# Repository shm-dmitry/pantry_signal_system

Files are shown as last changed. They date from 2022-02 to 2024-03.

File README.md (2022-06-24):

This is signal system for pantry.
It will control climate of pantry to smart house.

It will uses autonomous power system
1. car battery on 12v
2. temporary Li-Ion battary on 12v for charging primary battery
3. internal battery (6V..15V) which will used in case of primary and reserve 12V battery discharged. Used to send power alarm to smart house
4. Auto battary hot switch
5. Control over-discharge of all batteries
6. Provide information of current voltage to controller
7. Small current consumption. I plan to charge main battary once per ~6 month. 

It will collect and send next information (incl alarms):
1. Inside flooding alarm
2. Outside flooding alarm
3. Inside humidity level
4. Inside temperature
5. Inside light level
6. Open door alarm
7. Current voltage of all batteries
8. Current battery in use
9. Both 12V batteries discharged alarm 

It will automatically switch on air-drier basing on humidity level

It will have air fan system
1. Manual swotch on
2. Manual swotch off
3. Auto switch off after ~20 minutes

It will send all collected information to smart house system using LoRa channel

Project status

| Hardware | Status |
| --- | --- |
| Supply module | OK |
| Supply module :: Supply controller | OK |
| Logic module :: Flooding sensors | OK |
| Logic module :: Light sensor | OK |
| Logic module :: display | OK |
| Logic module :: humidity and temperature | OK |
| Logic module :: air dryer | OK |
| Logic module :: LoRa transmitter | OK |
| Logic module :: Open door alarm | OK |
| Logic module :: Wakeup button | OK |
| Air fan module | OK |
| LoRa receiver and smart house integration | OK |

| Firmware | Status |
| --- | --- |
| Supply controller | OK |
| Logic controller :: flooding sensors | OK |
| Logic controller :: light sensor | OK |
| Logic controller :: display | OK |
| Logic controller :: humidity and temperature | OK |
| Logic controller :: air dryer | OK |
| Logic controller :: LoRa transmitter | OK |
| Logic controller :: Open door alarm | OK |
| Logic controller :: Wakeup button and deep sleep mode | OK |
| Logic controller :: Integration with supply controller | OK |
| LoRa receiver and smart house integration | OK |

| Board | Status |
| --- | --- |
| Supply board | OK |
| logic module board | OK |
| fan board | OK |
| LoRa Receiver | OK |

| 3D models | Status |
| --- | --- |
| Supply board box | OK |
| Logic model box | OK |
| Air dryer | OK |
| Fan box | OK |
| Fan air intake | OK |
| LoRa receiver box | no |

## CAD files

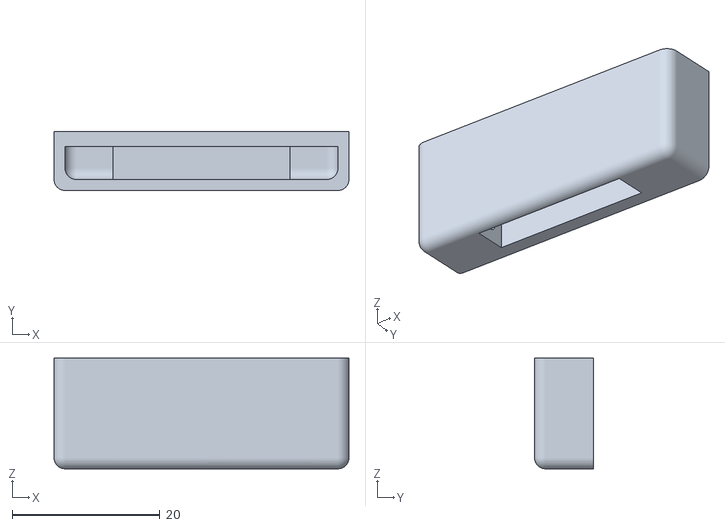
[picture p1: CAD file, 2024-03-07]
3d_models/reed_switch-reed-switch-holder.stl
40.0 x 8.00 x 15.0

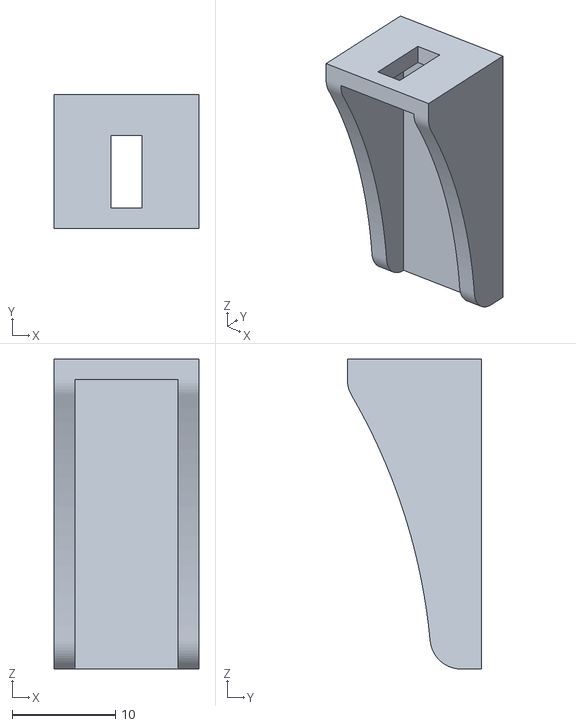
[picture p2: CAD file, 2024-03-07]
3d_models/reed_switch-magnet-holder.stl
14.0 x 13.0 x 30.0

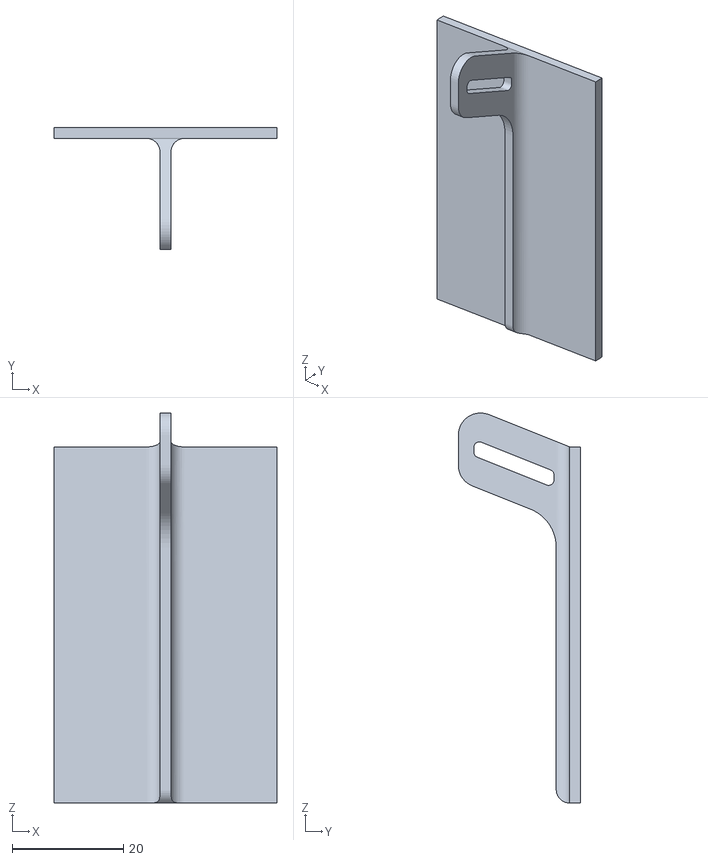
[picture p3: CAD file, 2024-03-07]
3d_models/reed_switch-magnet-holder-v3.stl
40.0 x 22.0 x 70.1

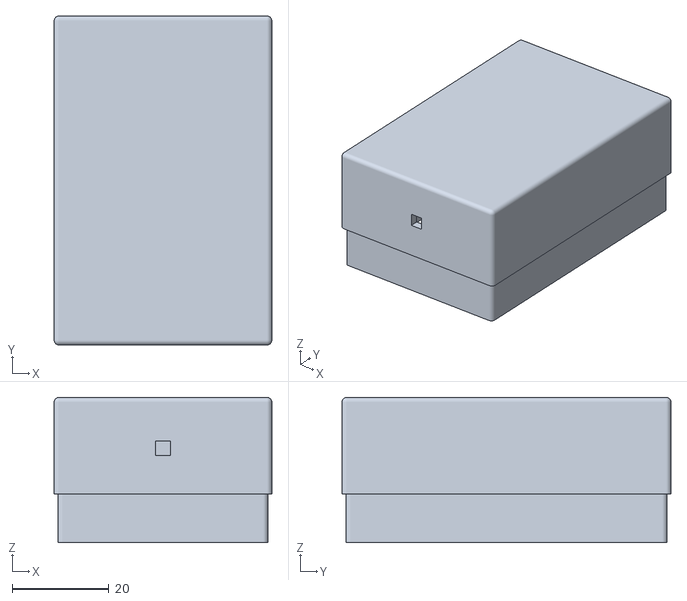
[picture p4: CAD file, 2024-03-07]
3d_models/lora_receiver-top.stl
45.0 x 68.0 x 30.0

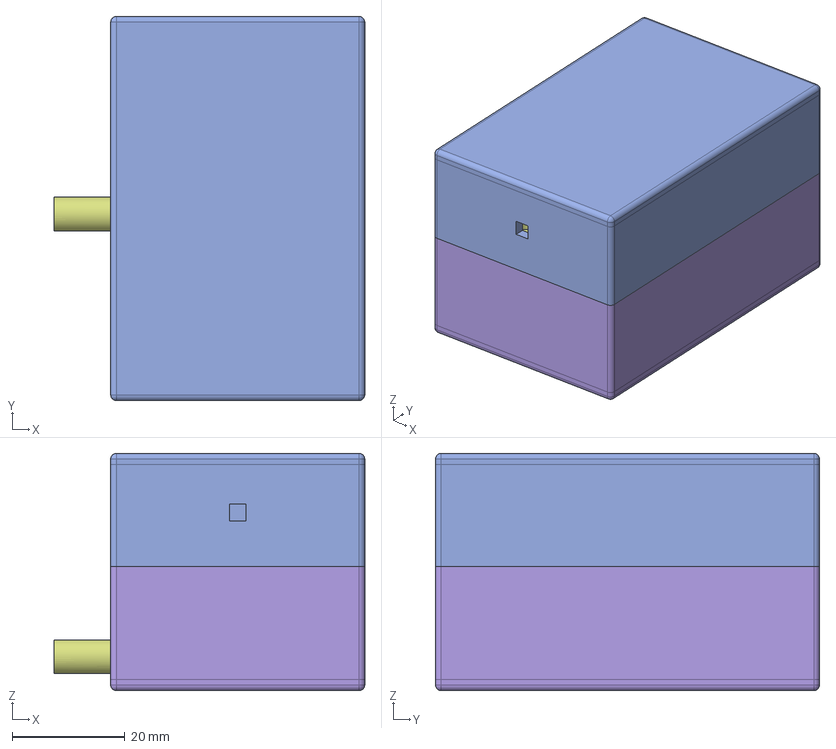
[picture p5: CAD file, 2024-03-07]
3d_models/lora_receiver.FCStd
55.0 x 68.0 x 42.0 mm
board
bottom
top

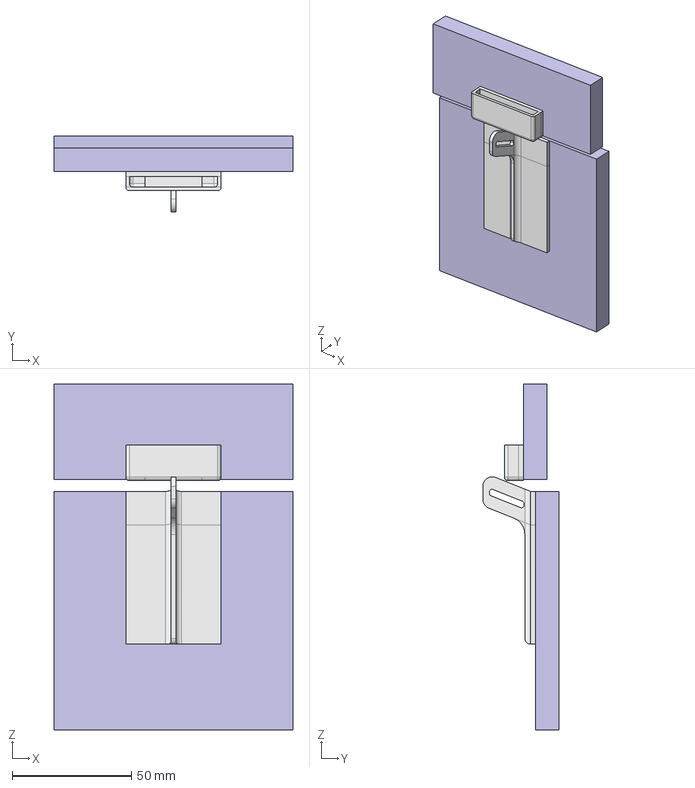
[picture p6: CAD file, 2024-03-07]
3d_models/reed_switch.FCStd
100.0 x 32.0 x 145.0 mm
reed-switch-holder
magnet-holder-v3

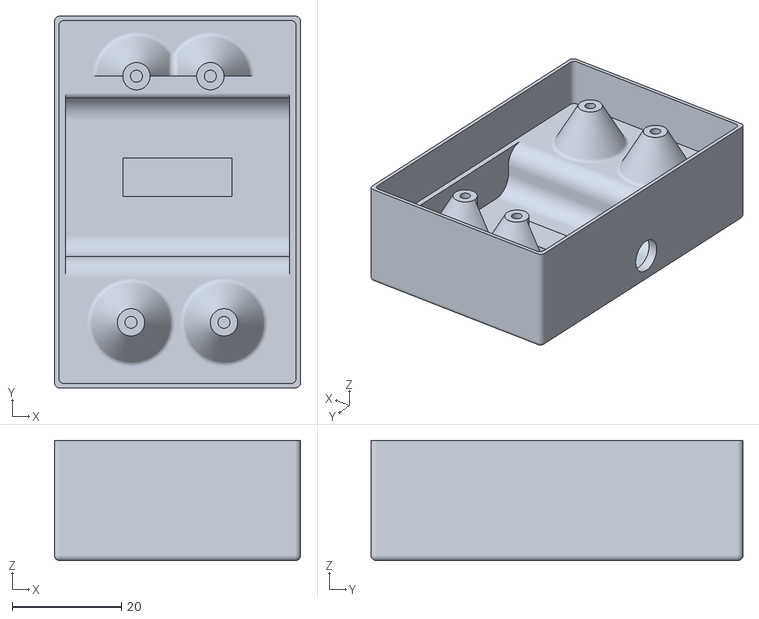
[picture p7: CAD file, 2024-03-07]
3d_models/lora_receiver-bottom.stl
45.0 x 68.0 x 22.0

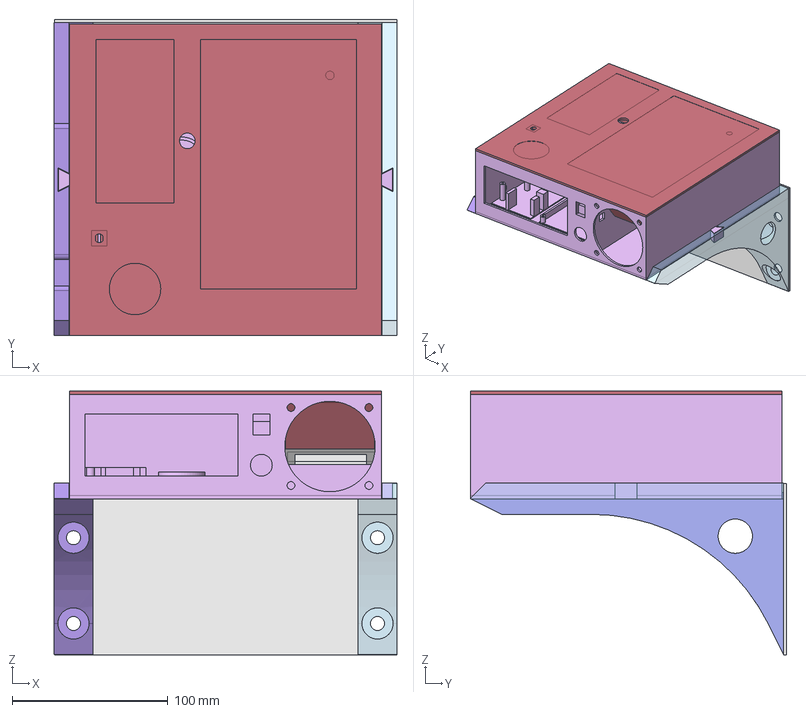
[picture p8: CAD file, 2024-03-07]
3d_models/pantry_box.FCStd
220.0 x 203.0 x 169.1 mm
cup
leg-left
leg-right-base
cilicogel-box
drill-mask

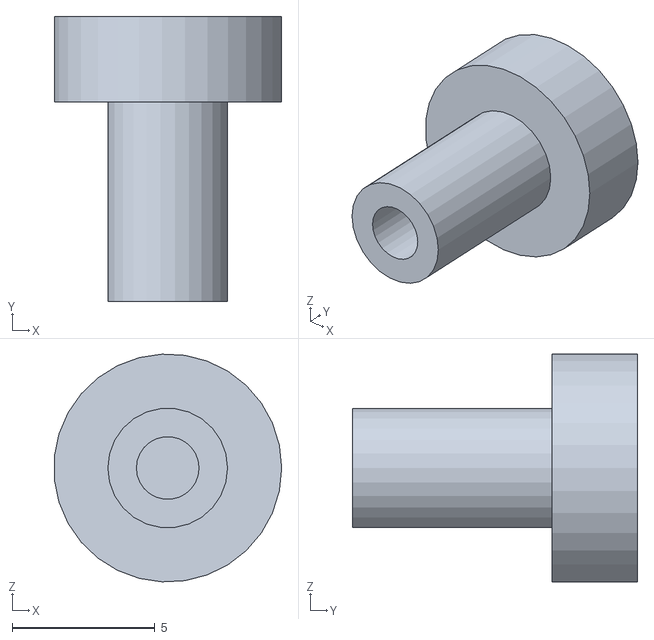
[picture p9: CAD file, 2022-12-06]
3d_models/pantry_box-pin.stl
7.98 x 10.0 x 7.99

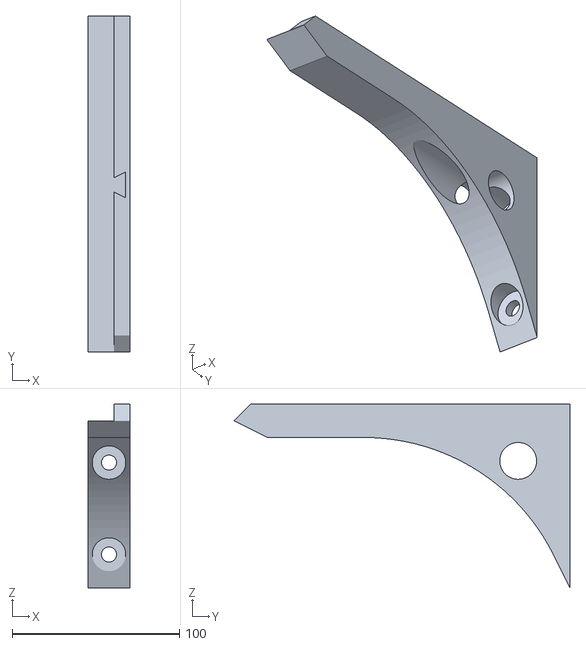
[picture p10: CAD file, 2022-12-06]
3d_models/pantry_box-leg-right.stl
25.0 x 201.0 x 110.0

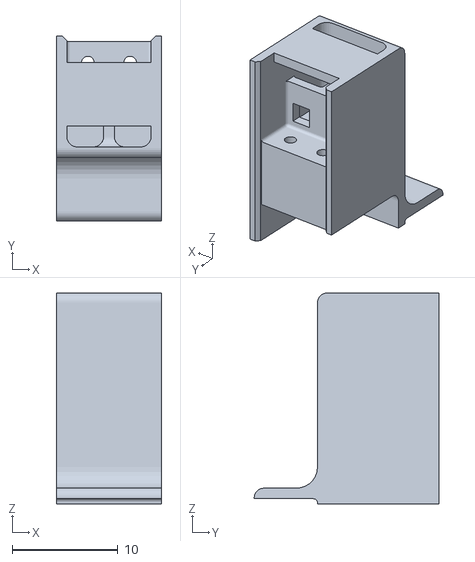
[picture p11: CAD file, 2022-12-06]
3d_models/flooding-sensor-left-side.stl
10.0 x 17.5 x 20.0

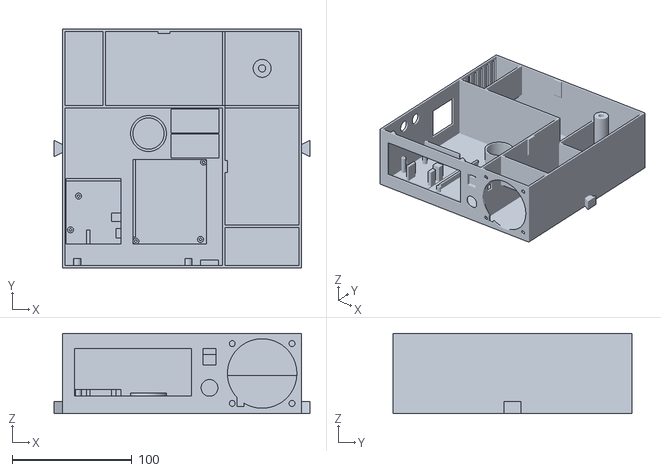
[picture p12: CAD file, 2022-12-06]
3d_models/pantry_box-box.stl
214.0 x 200.0 x 67.0

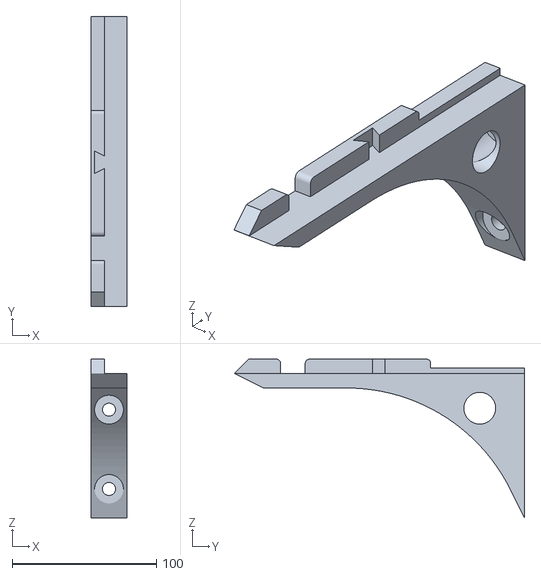
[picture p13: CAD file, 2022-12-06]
3d_models/pantry_box-leg-left.stl
25.0 x 201.0 x 110.0

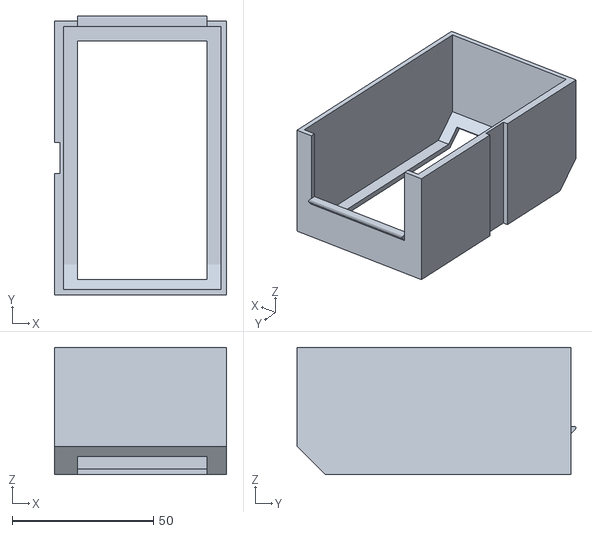
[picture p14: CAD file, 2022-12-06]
3d_models/pantry_box-cilicogel-box.stl
61.0 x 98.8 x 45.0

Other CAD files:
3d_models/flooding-sensor.FCStd
3d_models/pantry_box-cup.stl
3d_models/flooding-sensor-right-side.stl
3d_models/internal-flooding-sensor.FCStd
3d_models/23a-battery-container-box.stl
3d_models/23a-battery-container.FCStd
3d_models/air-dryer-box.stl
3d_models/air-dryer-container-cup.stl
3d_models/air-dryer-container.stl
3d_models/air-dryer-cup.stl
3d_models/air-dryer-pin.stl
3d_models/air-dryer.FCStd
3d_models/air-fan-box-box.stl
3d_models/air-fan-box-top.stl
3d_models/air-fan-box.FCStd
3d_models/air-fan-income-cap-support.stl
3d_models/air-fan-income-cap.stl
3d_models/air-fan-income-filter.stl
3d_models/air-fan-income-plate.stl
3d_models/air-fan-income-support.stl
3d_models/air-fan-income-top.stl
3d_models/air-fan-income.FCStd
3d_models/air-fan-outcome-cup.stl
3d_models/air-fan-outcome-filter.stl
3d_models/air-fan-outcome-plate.stl
3d_models/air-fan-outcome-support.stl
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

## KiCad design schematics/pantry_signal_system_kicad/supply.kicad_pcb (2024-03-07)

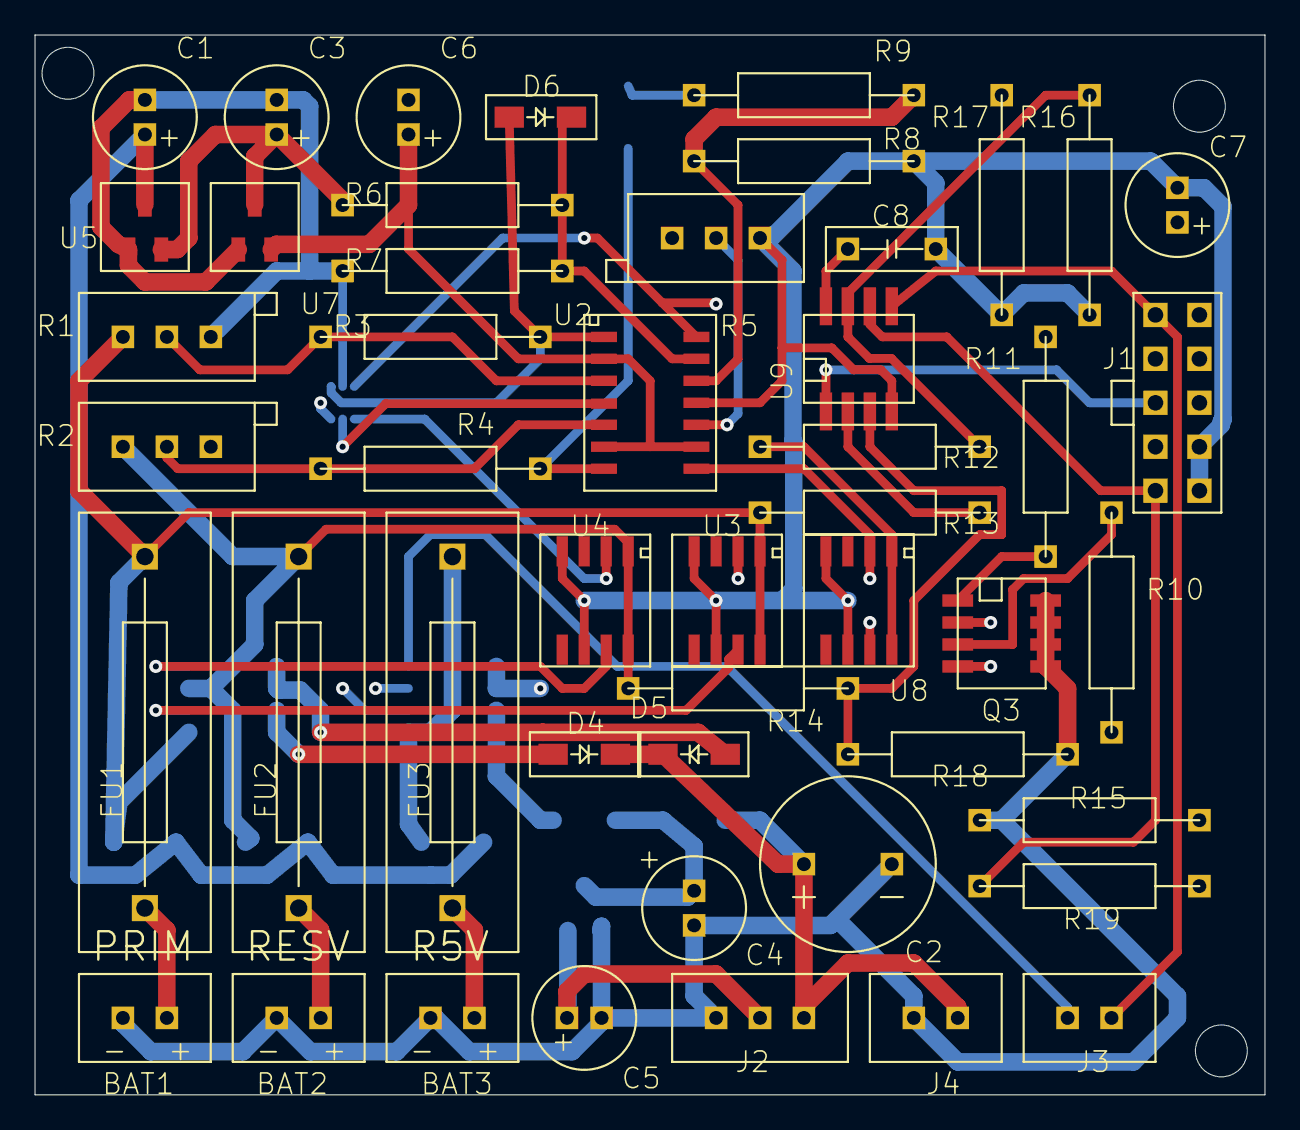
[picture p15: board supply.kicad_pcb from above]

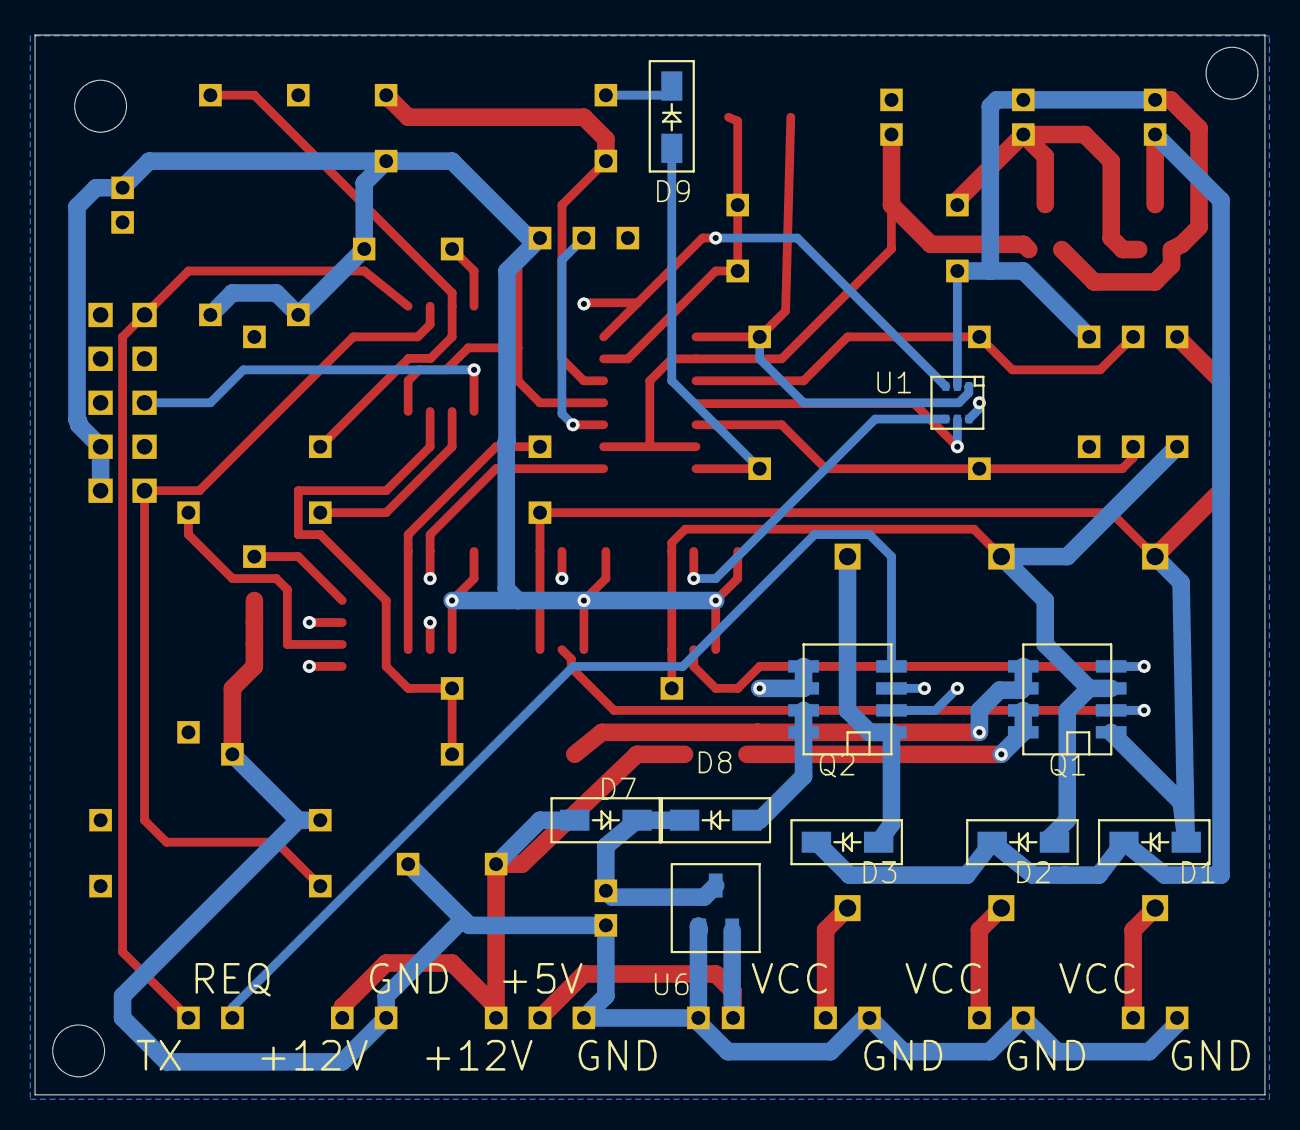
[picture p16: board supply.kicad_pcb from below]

Board: 4 copper layers, 71.1 x 61.3 mm, 61 parts (10 on the bottom side), 42 nets.

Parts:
@HOLE0, @HOLE1, @HOLE2: (no value)
BAT1, BAT2: 12V ... 15V; BATTERY
BAT3: 10V ... 15V; BATTERY
C1, C3, C4, C5, C6, C7: 10 uF; C-MINI-5X7
C2: 1000 uF; C
C8: 0.1 uF; C-1
D1, D2, D3, D4, D5, D6, D7, D8, D9: MBR130LSFT1G; D-SOD-123FL
FU1, FU2: H520PT / 1A; FU
FU3: H520PT / 0.5A; FU
J1: USBASP_PIN
J2: JST-XH254-3P
J3, J4: JST-XH254-2P
Q1, Q2, Q3: FDS4935A; SO-8
R1, R2, R5: 2M; RD-3296W-1-205LF
R3, R4, R6, R8, R9, R12, R13, R14: 2M; R
R7, R16, R17, R18: 1M; R
R10, R15: 10K; R
R11: 3K; R
R19: 620; R
U1: NC7WZ04; SC70
U2: AD8544SO-14; SO-14
U3, U4, U8: FAN73611; SOIC-8
U5, U6: MCP1703T-5002E/CB; SOT-23A
U7: MCP1703T-3302E/CB; SOT-23A
U9: ATTINY13SO-8-209; SO-8-209

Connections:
+5V: C5.PLUS, J2.PIN2, Q2.P3, U6.P2
+12V: C2.PIN_PLUS, D4.CATHODE, D5.CATHODE, D7.ANODE, J2.PIN1, J4.PIN2, R5.P2
BAT1: BAT1.PLUS, FU1.P$1
BAT2: BAT2.PLUS, FU2.P$1
BAT3: BAT3.PLUS, FU3.P$1
CURRENT_SUPPLY_IN_USE: J1.MISO, R19.P$2, U9.P6
GND: BAT1.MINUS, BAT2.MINUS, BAT3.MINUS, C1.MINUS, C2.PIN_GND, C3.MINUS, C4.MINUS, C5.MINUS, C6.MINUS, C7.MINUS, C8.P$2, J1.GND, J1.GND1, J2.PIN3, J4.PIN1, Q3.P5, Q3.P6, Q3.P7, Q3.P8, R1.P2, R2.P2, R5.P1, R7.P$1, R8.P$2, R15.P$1, R16.P$1, R17.P$1, R18.P$1, U1.P2, U2.P11, U3.P_4, U3.P_6, U4.P_4, U4.P_6, U5.P1, U6.P1, U7.P1, U8.P_4, U8.P_6, U9.P4
IS_12V_POWER_OK: R5.P3, U2.P10
IS_ENABLE_RESERVE_+5V_INV: Q3.P2, U2.P8, U8.P_2
IS_PRIMARY_BATTERY_OK: D6.ANODE, R3.P$2, U1.P1, U2.P1
IS_RESERVE_BATTERY_OK: D9.ANODE, R4.P$1, U2.P7
IS_USE_RESERVE_BATTERY: Q3.P4, U1.P3, U2.P14
unnamed: C1.PLUS, D1.CATHODE, D2.CATHODE, D3.CATHODE, U5.P3
unnamed: D6.CATHODE, R6.P$2, R7.P$2, U2.P13
unnamed: R1.P3, R3.P$1, U2.P3
unnamed: C4.PLUS, D7.CATHODE, D8.CATHODE, U6.P3
unnamed: R2.P3, R4.P$2, U2.P5
unnamed: R8.P$1, R9.P$1, U2.P12
unnamed: D4.ANODE, Q1.P7, Q1.P8
unnamed: D5.ANODE, Q1.P5, Q1.P6
unnamed: J1.RST, U9.P1
unnamed: U1.P6, U3.P_2
unnamed: U1.P4, U4.P_2
unnamed: Q3.P3, R10.P$1
unnamed: D8.ANODE, Q2.P7, Q2.P8
unnamed: Q3.P1, R11.P$1
unnamed: D9.CATHODE, R9.P$2
unnamed: C7.PLUS, R10.P$2, R11.P$2, R15.P$2, R19.P$1
PRIMARY_SUPPLY_12V: D1.ANODE, FU1.P$2, Q1.P1, R1.P1, R13.P$2, U3.P_1, U3.P_8
PRIMARY_VOLTAGE_LEVEL: R13.P$1, R17.P$2, U9.P2
REQUEST_SUPPLY_MEASURE_INV: J3.PIN2, Q2.P4
RESERVE_+5V_LEVEL: J1.SCK, R12.P$1, R16.P$2, U9.P7
RESERVE_+5V_SUPPLY: D3.ANODE, FU3.P$2, Q2.P1, R12.P$2, U8.P_1, U8.P_8
RESERVE_SUPPLY_12V: D2.ANODE, FU2.P$2, Q1.P3, R2.P1, R14.P$2, U4.P_1, U4.P_8
RESERVE_VOLTAGE_LEVEL: R14.P$1, R18.P$2, U9.P3
SUPPLY_AVR_+5V: C8.P$1, J1.VCC, Q2.P5, Q2.P6, U9.P8
SUPPLY_CONTROL_3V3: C6.PLUS, U2.P2, U2.P6, U2.P9, U7.P2
SUPPLY_CONTROL_+5V: C3.PLUS, R6.P$1, U1.P5, U2.P4, U5.P2, U7.P3
SUPPLY_UART_TX: J1.MOSI, J3.PIN1, U9.P5
USE_PRIMARY_BATTERY: Q1.P2, U3.P_7
USE_RESERVE_5V_BATTERY: Q2.P2, U8.P_7
USE_RESERVE_BATTERY: Q1.P4, U4.P_7

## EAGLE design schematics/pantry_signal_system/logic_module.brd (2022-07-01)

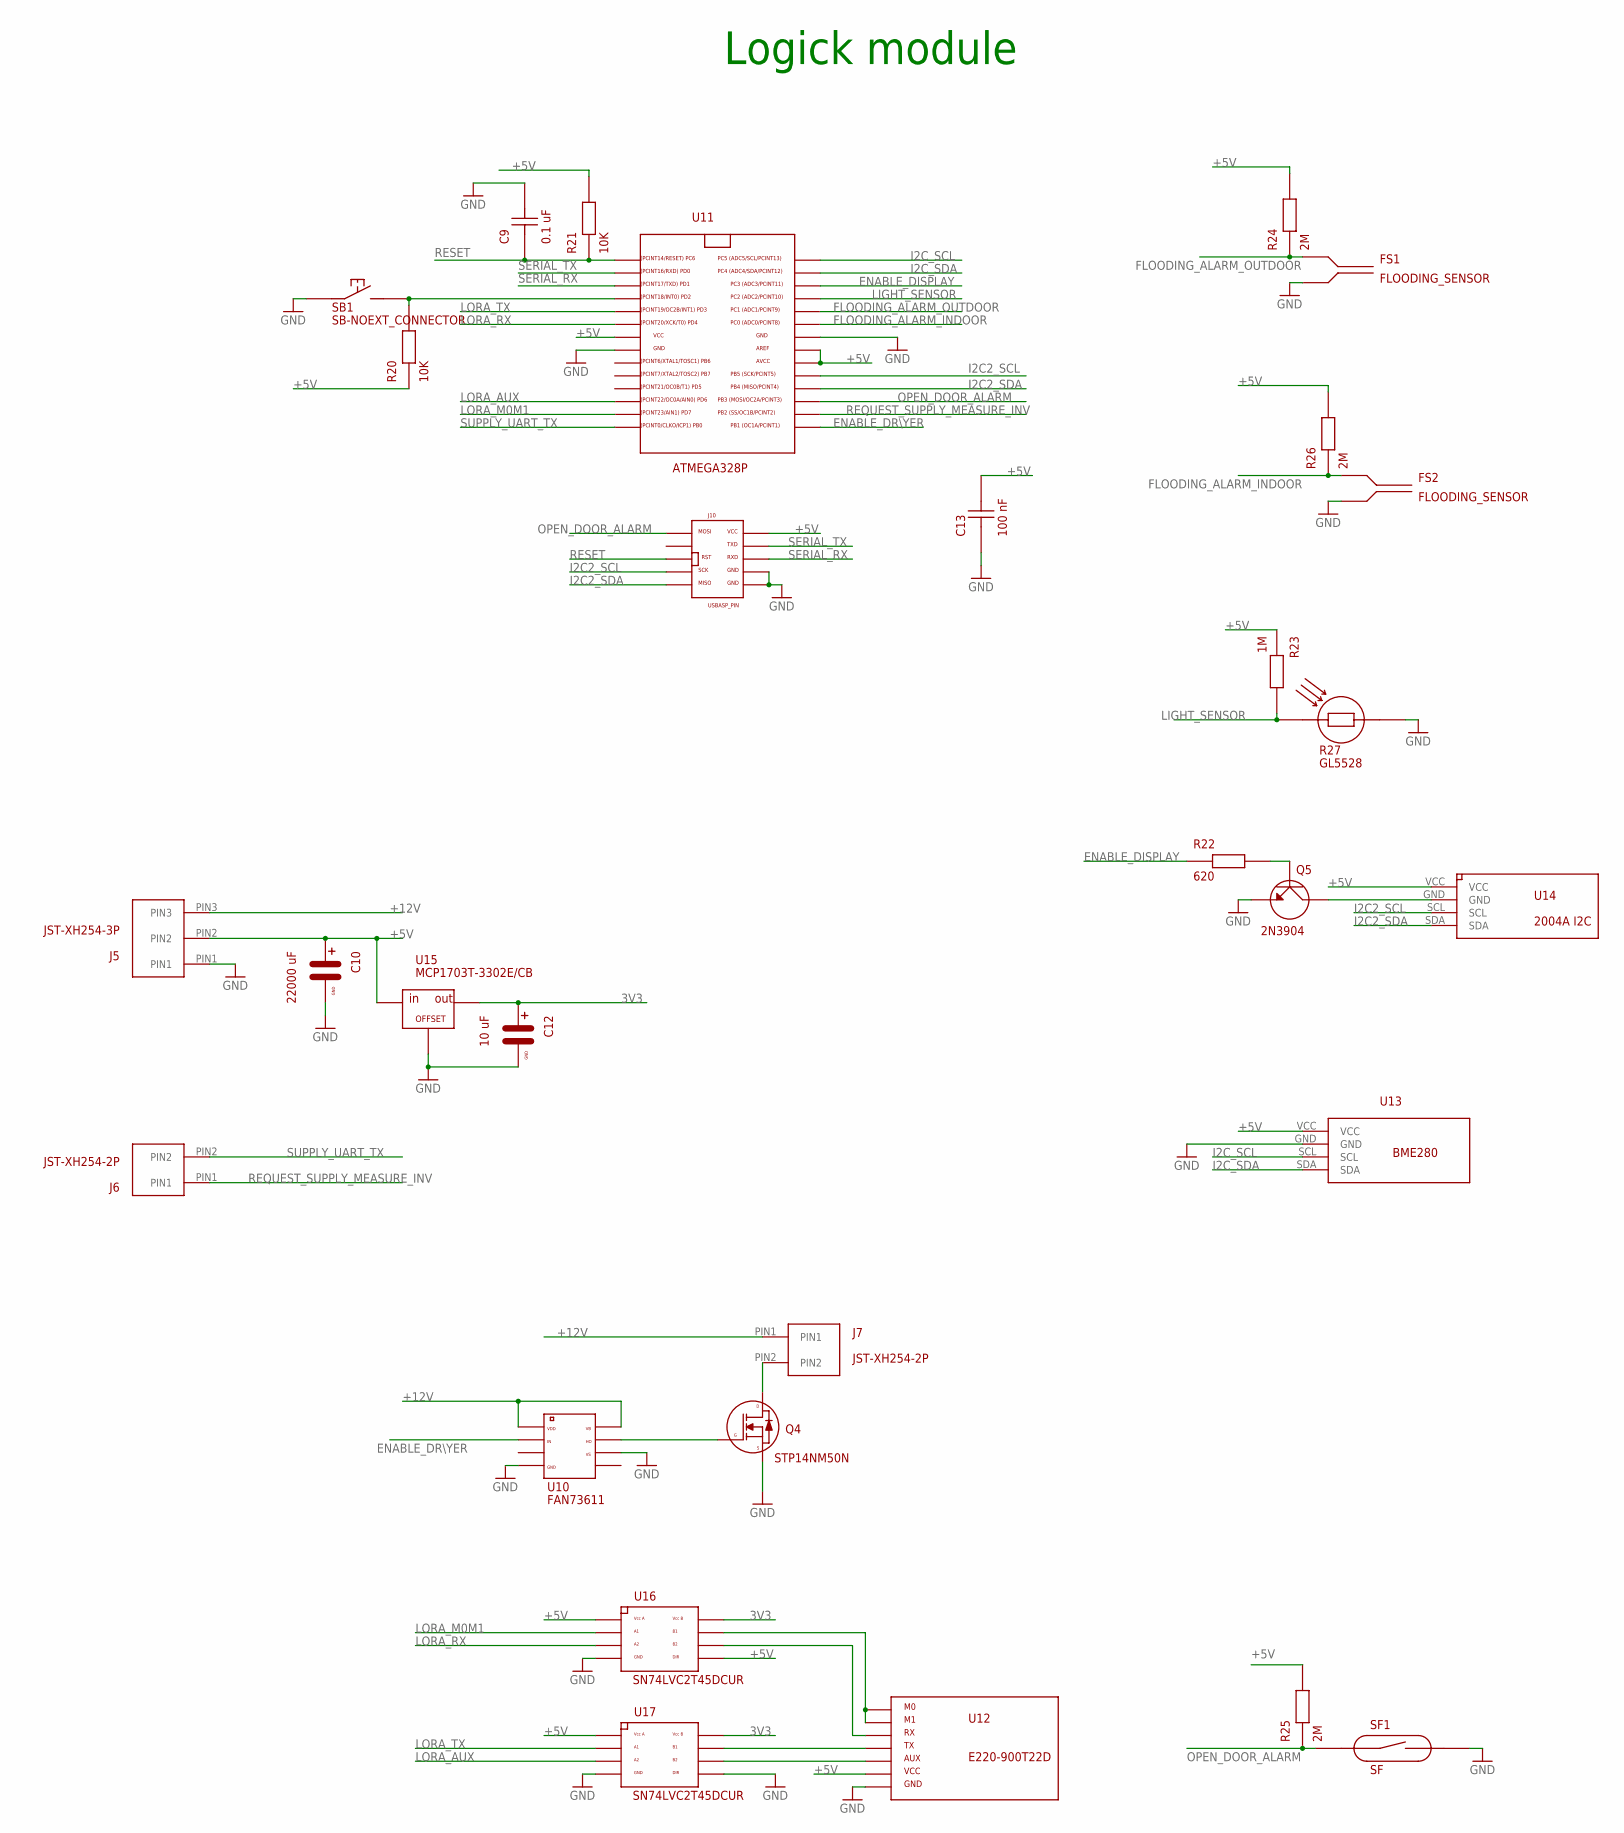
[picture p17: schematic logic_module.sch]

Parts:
C9: 0.1 uF; C-1
C10: 22000 uF; C-MINI-5X7
C12: 10 uF; C-MINI-5X7
C13: 100 nF; C-1
FS1, FS2: FLOODING_SENSOR
J5: JST-XH254-3P
J6, J7: JST-XH254-2P
J10: USBASP_PIN
Q4: STP14NM50N; MOSFET_N
Q5: 2N3904; TRANSISTOR
R20, R21: 10K; R
R22: 620; R
R23: 1M; R
R24, R25, R26: 2M; R
R27: GL5528; RF
SB1: SB-NOEXT_CONNECTOR; SB-EXT
SF1: SF
U10: FAN73611; SOIC-8
U11: ATMEGA328P
U12: E220-900T22D; LORA
U13: BME280BME280-CONNECTOR-ONLY; BME280-CONNECTOR-ONLY
U14: 2004A I2C; I2C_DISPLAY
U15: MCP1703T-3302E/CB; SOT-23A
U16, U17: SN74LVC2T45DCUR; VSSOP-8

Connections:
3V3: C12.PLUS (PIN_PLUS), U15.P2 (OUT), U16.P8 (VCCB), U17.P8 (VCCB)
+5V: C10.PLUS (PIN_PLUS), C13.P$2, J5.PIN2, J10.VCC, R20.P$1, R21.P$2, R23.P$1, R24.P$2, R25.P$2, R26.P$2, U11.AREF, U11.AVCC, U11.VCC, U12.VCC, U13.VCC, U14.VCC, U15.P3 (IN), U16.P1 (VCCA), U16.P5 (DIR), U17.P1 (VCCA)
+12V: J5.PIN3, J7.PIN1, U10.P_1 (VDD), U10.P_8 (VB)
ENABLE_DISPLAY: R22.P$1, U11.PC3
ENABLE_DR\YER: U10.P_2 (IN), U11.PB1
FLOODING_ALARM_INDOOR: FS2.P$1, R26.P$1, U11.PC0
FLOODING_ALARM_OUTDOOR: FS1.P$1, R24.P$1, U11.PC1
GND: C9.P$2, C10.MINUS (PIN_GND), C12.MINUS (PIN_GND), C13.P$1, FS1.P$2, FS2.P$2, J5.PIN1, J10.GND, J10.GND1, Q4.S, Q5.E, R27.PIN2, SB1.P$1, SF1.P$2, U10.P_4 (GND), U10.P_6 (VS), U11.GND, U11.GND1, U12.GND, U13.GND, U15.P1 (GND), U16.P4 (GND), U17.P4 (GND), U17.P5 (DIR)
I2C2_SCL: J10.SCK, U11.PB5, U14.SCL
I2C2_SDA: J10.MISO, U11.PB4, U14.SDA
I2C_SCL: U11.PC5, U13.SCL
I2C_SDA: U11.PC4, U13.SDA
LIGHT_SENSOR: R23.P$2, R27.PIN1, U11.PC2
LORA_AUX: U11.PD6, U17.P3 (A2)
LORA_M0M1: U11.PD7, U16.P2 (A1)
LORA_RX: U11.PD4, U16.P3 (A2)
LORA_TX: U11.PD3, U17.P2 (A1)
unnamed: U12.TX, U17.P7 (B1)
unnamed: U12.RX, U16.P6 (B2)
unnamed: U12.AUX, U17.P6 (B2)
unnamed: J7.PIN2, Q4.D
unnamed: Q4.G, U10.P_7 (HO)
unnamed: U12.M0, U12.M1, U16.P7 (B1)
unnamed: Q5.C, U14.GND
unnamed: Q5.B, R22.P$2
unnamed: R20.P$2, SB1.P$2, U11.PD2
OPEN_DOOR_ALARM: J10.MOSI, R25.P$1, SF1.P$1, U11.PB3
REQUEST_SUPPLY_MEASURE_INV: J6.PIN1, U11.PB2
RESET: C9.P$1, J10.RST (RESET), R21.P$1, U11.PC6
SERIAL_RX: J10.RXD, U11.PD1
SERIAL_TX: J10.TXD, U11.PD0
SUPPLY_UART_TX: J6.PIN2, U11.PB0

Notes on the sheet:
Logick module

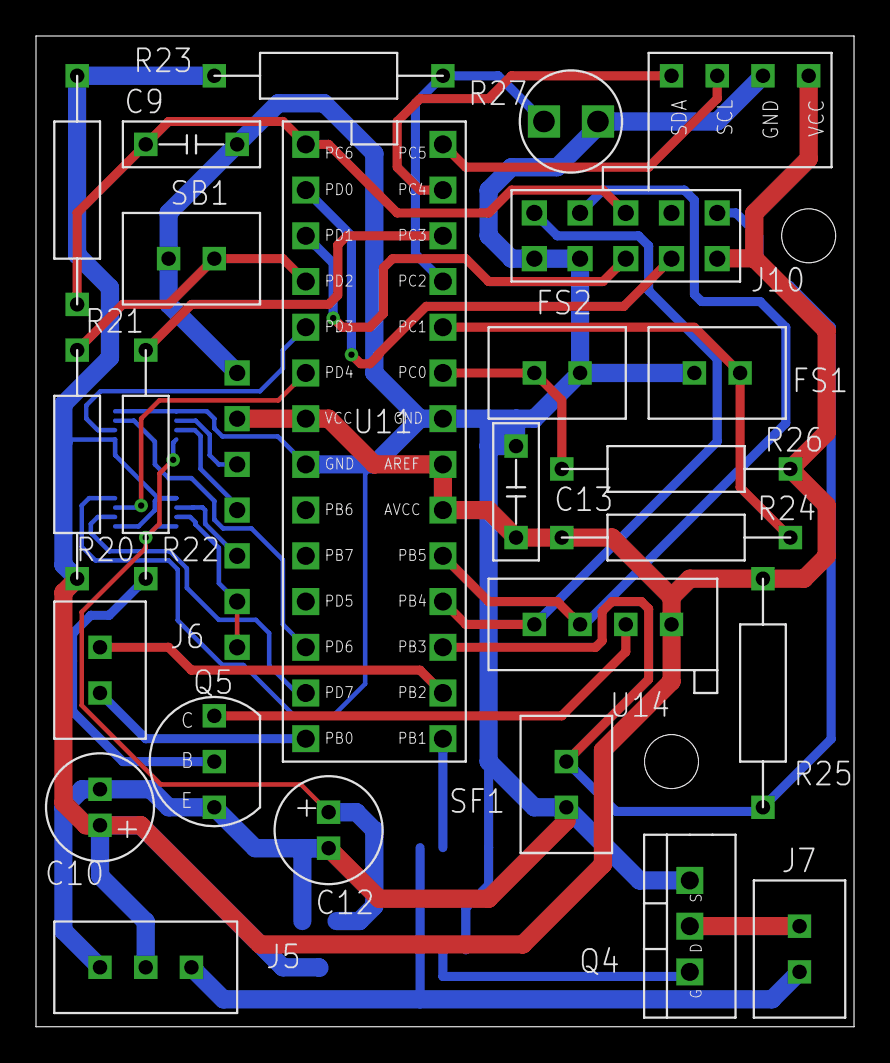
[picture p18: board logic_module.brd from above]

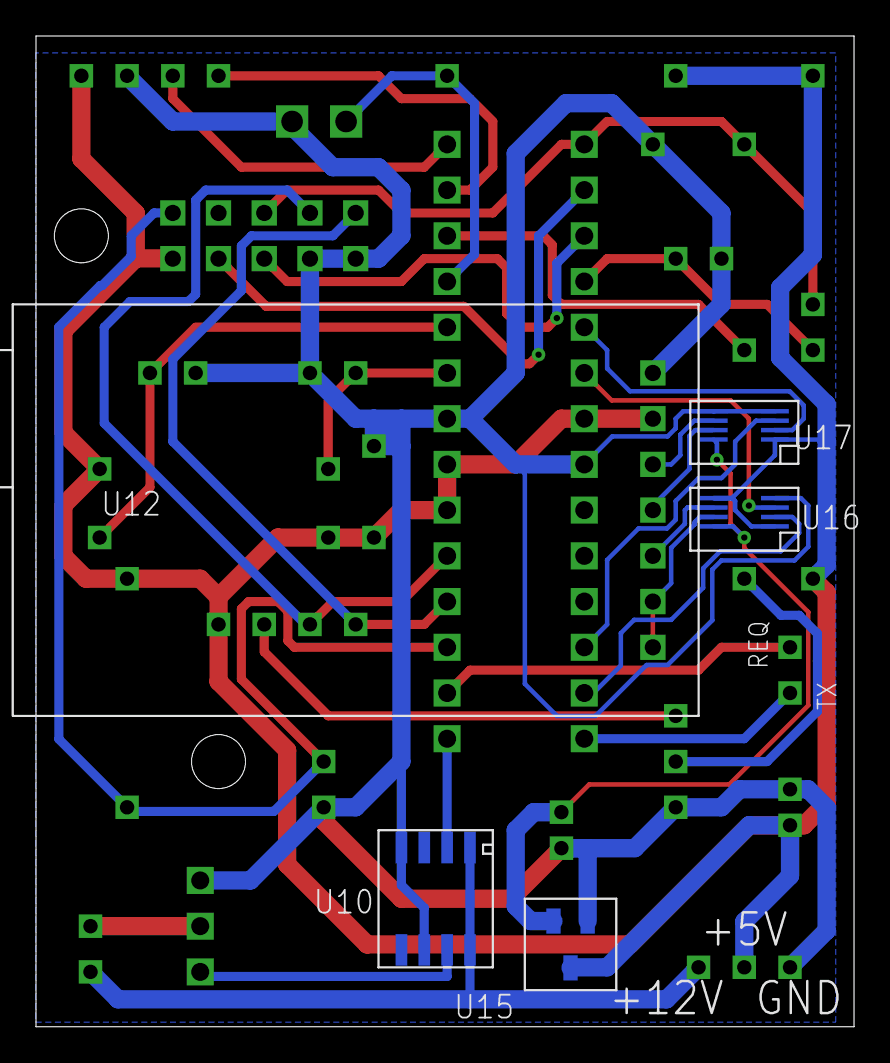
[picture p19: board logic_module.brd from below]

Board: 2 copper layers, 45.4 x 55.0 mm, 30 parts (5 on the bottom side), 32 nets.

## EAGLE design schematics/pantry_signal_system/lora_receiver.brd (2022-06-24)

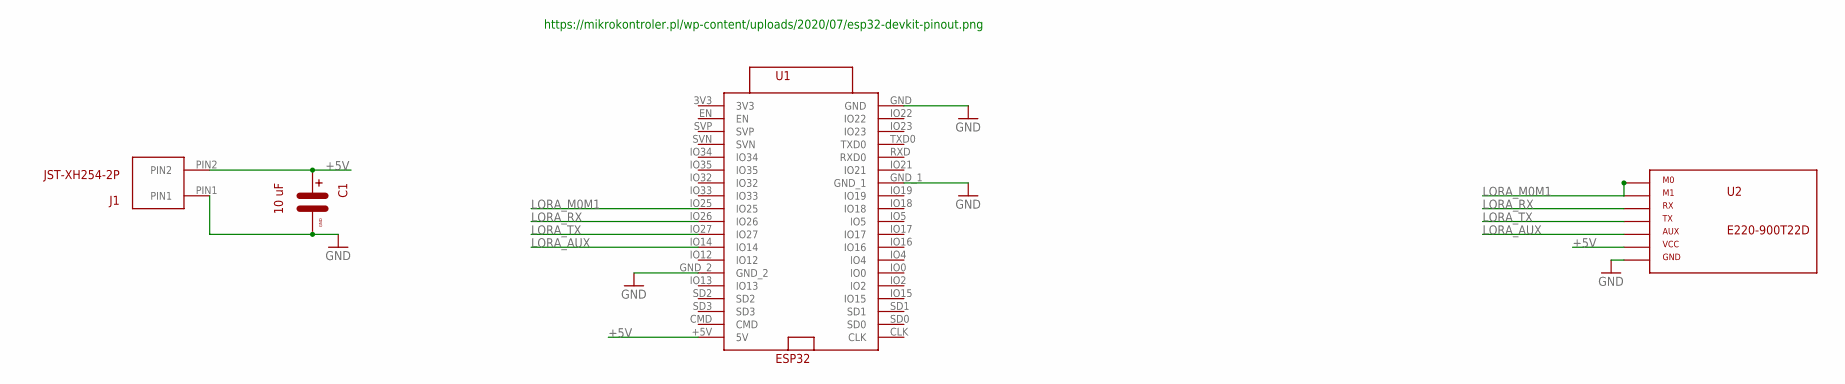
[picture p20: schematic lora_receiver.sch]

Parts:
C1: 10 uF; C-MINI-5X7
J1: JST-XH254-2P
U1: ESP32
U2: E220-900T22D; LORA

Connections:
3V3: U1.3V3
+5V: C1.PLUS (PIN_PLUS), J1.PIN2, U1.+5V (5V), U2.VCC
GND: C1.MINUS (PIN_GND), J1.PIN1, U1.GND, U1.GND_1, U1.GND_2, U2.GND
LORA_AUX: U1.IO14, U2.AUX
LORA_M0M1: U1.IO25, U2.M0, U2.M1
LORA_RX: U1.IO26, U2.RX
LORA_TX: U1.IO27, U2.TX

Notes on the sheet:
https://mikrokontroler.pl/wp-content/uploads/2020/07/esp32-devkit-pinout.png

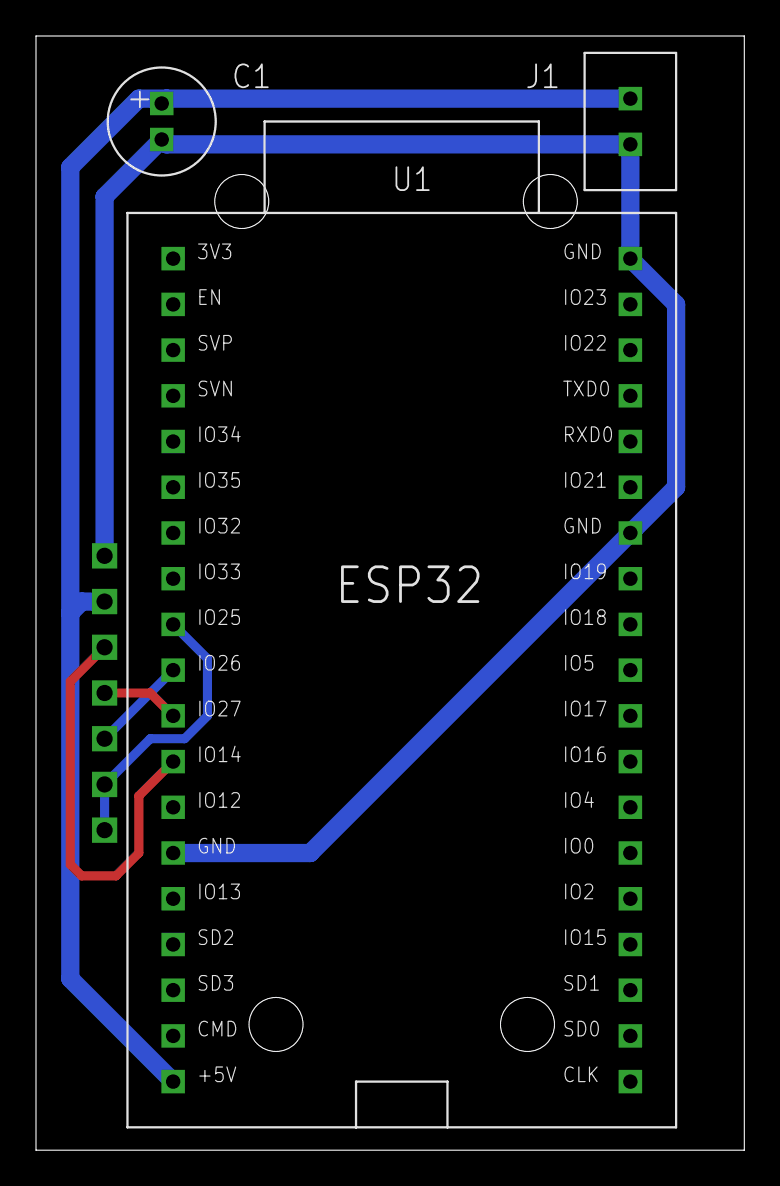
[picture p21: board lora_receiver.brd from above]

Board: 2 copper layers, 39.4 x 61.9 mm, 4 parts (1 on the bottom side), 6 nets.

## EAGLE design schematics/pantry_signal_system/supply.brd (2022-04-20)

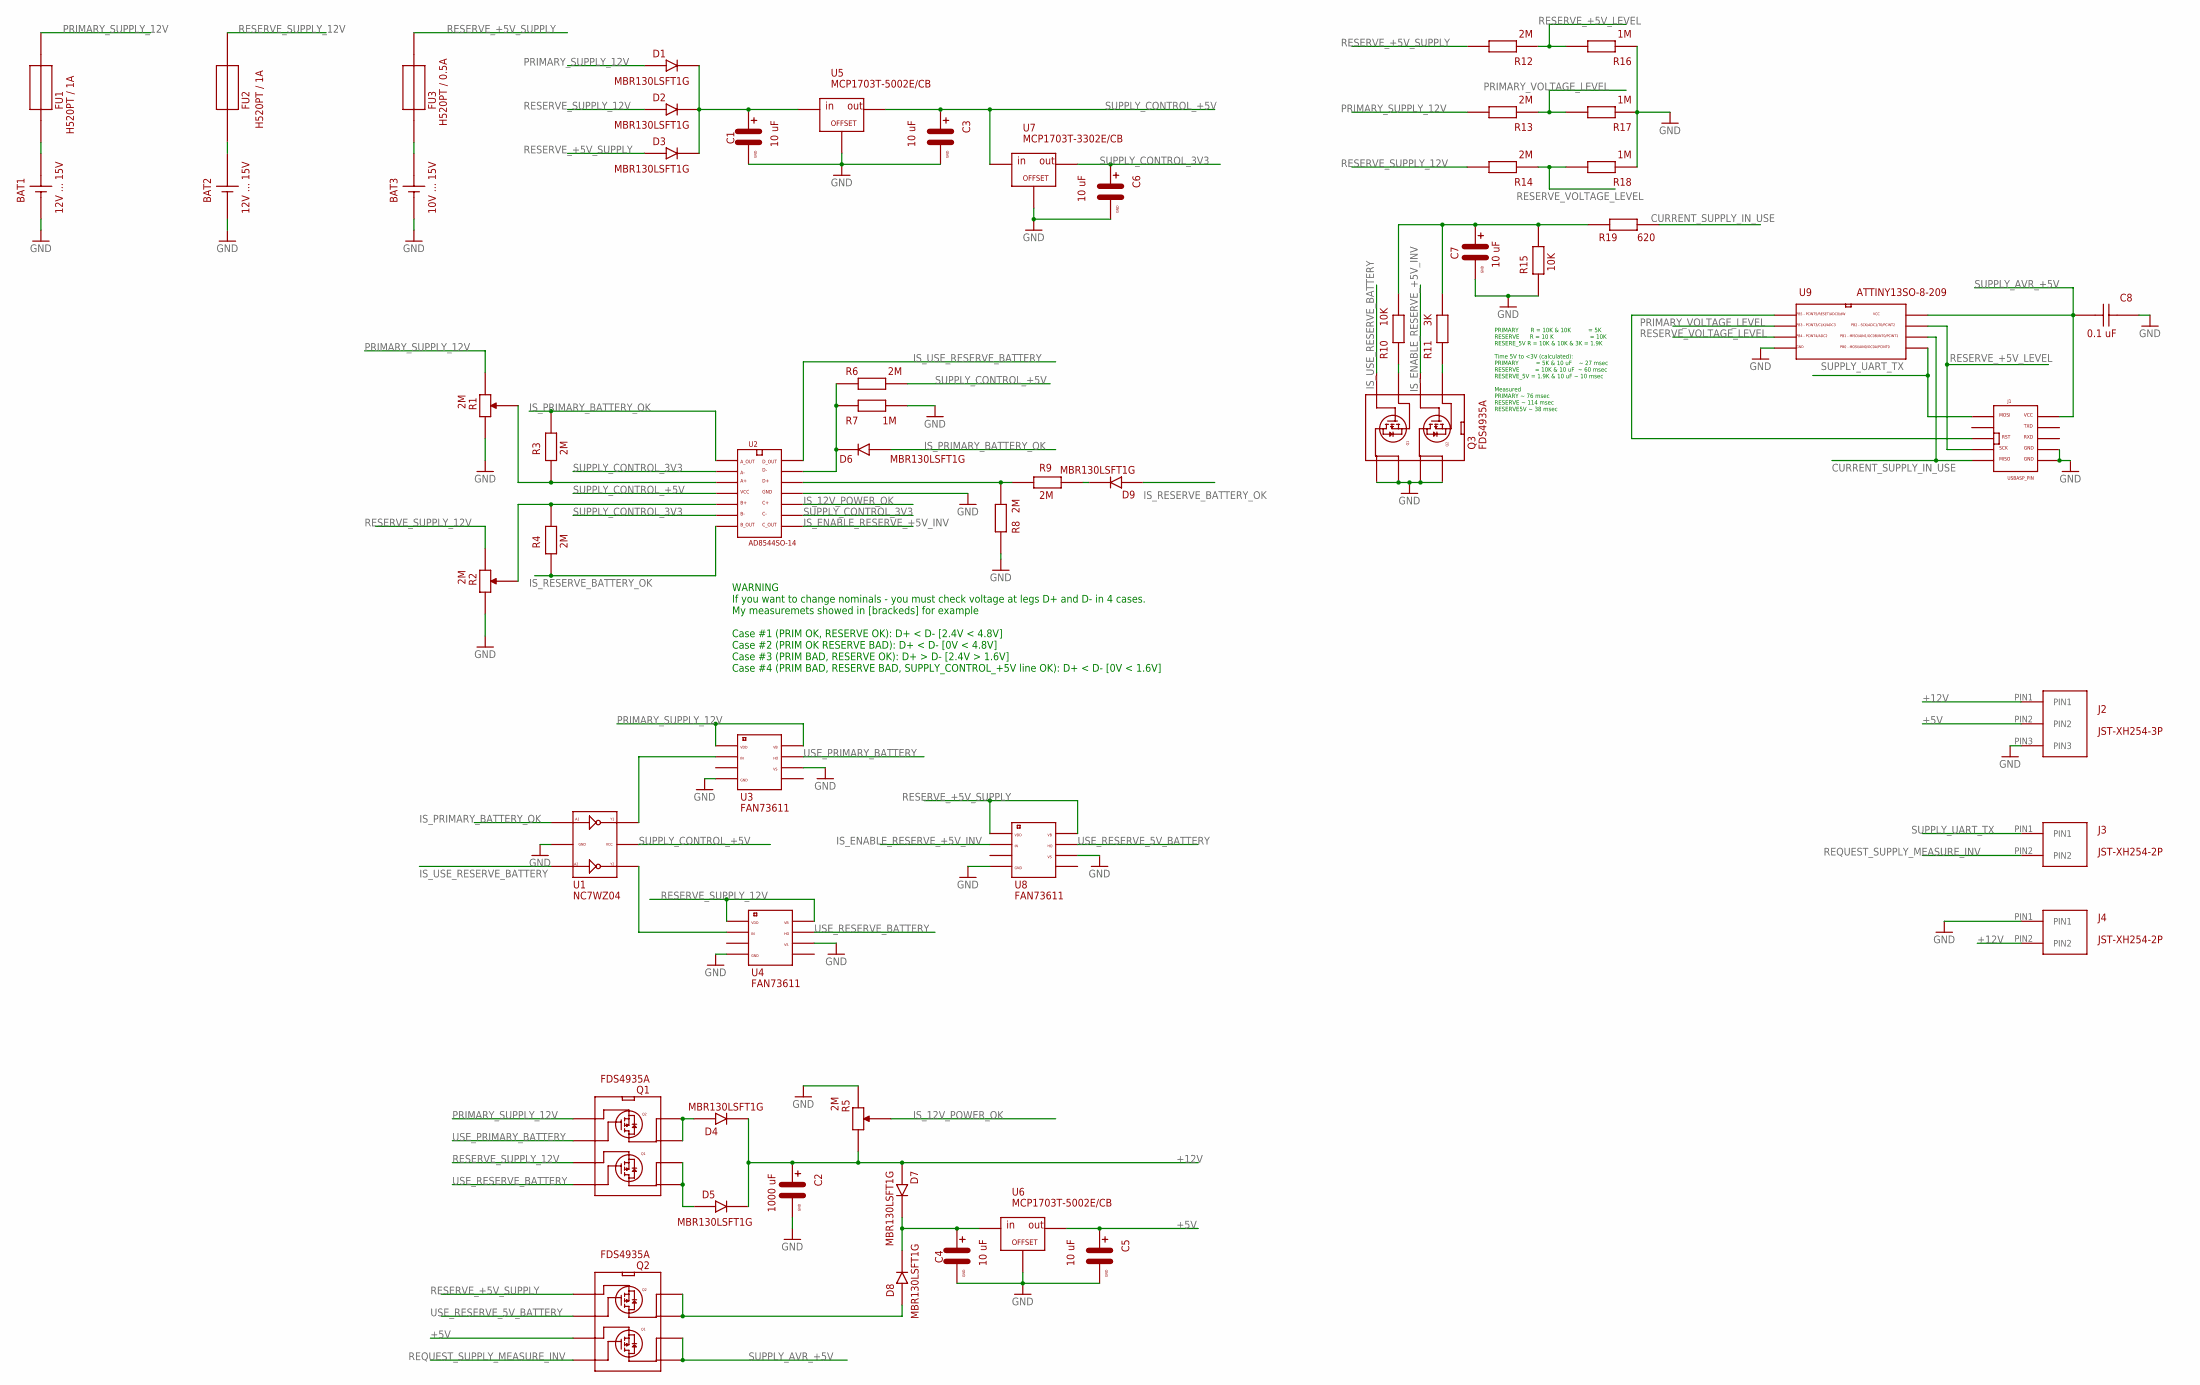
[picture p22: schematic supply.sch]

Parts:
BAT1, BAT2: 12V ... 15V; BATTERY
BAT3: 10V ... 15V; BATTERY
C1, C3, C4, C5, C6, C7: 10 uF; C-MINI-5X7
C2: 1000 uF; C
C8: 0.1 uF; C-1
D1, D2, D3, D4, D5, D6, D7, D8, D9: MBR130LSFT1G; D-SOD-123FL
FU1, FU2: H520PT / 1A; FU
FU3: H520PT / 0.5A; FU
J1: USBASP_PIN
J2: JST-XH254-3P
J3, J4: JST-XH254-2P
Q1, Q2, Q3: FDS4935A; SO-8
R1, R2, R5: 2M; RD-3296W-1-205LF
R3, R4, R6, R8, R9, R12, R13, R14: 2M; R
R7, R16, R17, R18: 1M; R
R10, R15: 10K; R
R11: 3K; R
R19: 620; R
U1: NC7WZ04; SC70
U2: AD8544SO-14; SO-14
U3, U4, U8: FAN73611; SOIC-8
U5, U6: MCP1703T-5002E/CB; SOT-23A
U7: MCP1703T-3302E/CB; SOT-23A
U9: ATTINY13SO-8-209; SO-8-209

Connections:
+5V: C5.PLUS (PIN_PLUS), J2.PIN2, Q2.P3 (S1), U6.P2 (OUT)
+12V: C2.PIN_PLUS, D4.CATHODE, D5.CATHODE, D7.ANODE, J2.PIN1, J4.PIN2, R5.P2
BAT1: BAT1.PLUS, FU1.P$1
BAT2: BAT2.PLUS, FU2.P$1
BAT3: BAT3.PLUS, FU3.P$1
CURRENT_SUPPLY_IN_USE: J1.MISO, R19.P$2, U9.P6 (PB1)
GND: BAT1.MINUS, BAT2.MINUS, BAT3.MINUS, C1.MINUS (PIN_GND), C2.PIN_GND, C3.MINUS (PIN_GND), C4.MINUS (PIN_GND), C5.MINUS (PIN_GND), C6.MINUS (PIN_GND), C7.MINUS (PIN_GND), C8.P$2, J1.GND, J1.GND1, J2.PIN3, J4.PIN1, Q3.P5 (D11), Q3.P6 (D12), Q3.P7 (D21), Q3.P8 (D22), R1.P2, R2.P2, R5.P1, R7.P$1, R8.P$2, R15.P$1, R16.P$1, R17.P$1, R18.P$1, U1.P2 (GND), U2.P11 (GND), U3.P_4 (GND), U3.P_6 (VS), U4.P_4 (GND), U4.P_6 (VS), U5.P1 (GND), U6.P1 (GND), U7.P1 (GND), U8.P_4 (GND), U8.P_6 (VS), U9.P4 (GND)
IS_12V_POWER_OK: R5.P3, U2.P10 (C+)
IS_ENABLE_RESERVE_+5V_INV: Q3.P2 (G2), U2.P8 (C_OUT), U8.P_2 (IN)
IS_PRIMARY_BATTERY_OK: D6.ANODE, R3.P$2, U1.P1 (A1), U2.P1 (A_OUT)
IS_RESERVE_BATTERY_OK: D9.ANODE, R4.P$1, U2.P7 (B_OUT)
IS_USE_RESERVE_BATTERY: Q3.P4 (G1), U1.P3 (A2), U2.P14 (D_OUT)
unnamed: C1.PLUS (PIN_PLUS), D1.CATHODE, D2.CATHODE, D3.CATHODE, U5.P3 (IN)
unnamed: D6.CATHODE, R6.P$2, R7.P$2, U2.P13 (D-)
unnamed: R1.P3, R3.P$1, U2.P3 (A+)
unnamed: C4.PLUS (PIN_PLUS), D7.CATHODE, D8.CATHODE, U6.P3 (IN)
unnamed: R2.P3, R4.P$2, U2.P5 (B+)
unnamed: R8.P$1, R9.P$1, U2.P12 (D+)
unnamed: D4.ANODE, Q1.P7 (D21), Q1.P8 (D22)
unnamed: D5.ANODE, Q1.P5 (D11), Q1.P6 (D12)
unnamed: J1.RST (RESET), U9.P1 (PB5)
unnamed: U1.P6 (Y1), U3.P_2 (IN)
unnamed: U1.P4 (Y2), U4.P_2 (IN)
unnamed: Q3.P3 (S1), R10.P$1
unnamed: D8.ANODE, Q2.P7 (D21), Q2.P8 (D22)
unnamed: Q3.P1 (S2), R11.P$1
unnamed: D9.CATHODE, R9.P$2
unnamed: C7.PLUS (PIN_PLUS), R10.P$2, R11.P$2, R15.P$2, R19.P$1
PRIMARY_SUPPLY_12V: D1.ANODE, FU1.P$2, Q1.P1 (S2), R1.P1, R13.P$2, U3.P_1 (VDD), U3.P_8 (VB)
PRIMARY_VOLTAGE_LEVEL: R13.P$1, R17.P$2, U9.P2 (PB3)
REQUEST_SUPPLY_MEASURE_INV: J3.PIN2, Q2.P4 (G1)
RESERVE_+5V_LEVEL: J1.SCK, R12.P$1, R16.P$2, U9.P7 (PB2)
RESERVE_+5V_SUPPLY: D3.ANODE, FU3.P$2, Q2.P1 (S2), R12.P$2, U8.P_1 (VDD), U8.P_8 (VB)
RESERVE_SUPPLY_12V: D2.ANODE, FU2.P$2, Q1.P3 (S1), R2.P1, R14.P$2, U4.P_1 (VDD), U4.P_8 (VB)
RESERVE_VOLTAGE_LEVEL: R14.P$1, R18.P$2, U9.P3 (PB4)
SUPPLY_AVR_+5V: C8.P$1, J1.VCC, Q2.P5 (D11), Q2.P6 (D12), U9.P8 (VCC)
SUPPLY_CONTROL_3V3: C6.PLUS (PIN_PLUS), U2.P2 (A-), U2.P6 (B-), U2.P9 (C-), U7.P2 (OUT)
SUPPLY_CONTROL_+5V: C3.PLUS (PIN_PLUS), R6.P$1, U1.P5 (VCC), U2.P4 (VCC), U5.P2 (OUT), U7.P3 (IN)
SUPPLY_UART_TX: J1.MOSI, J3.PIN1, U9.P5 (PB0)
USE_PRIMARY_BATTERY: Q1.P2 (G2), U3.P_7 (HO)
USE_RESERVE_5V_BATTERY: Q2.P2 (G2), U8.P_7 (HO)
USE_RESERVE_BATTERY: Q1.P4 (G1), U4.P_7 (HO)

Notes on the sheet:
PRIMARY R = 10K & 10K = 5K RESERVE R = 10 K = 10K RESERE_5V R = 10K & 10K & 3K = 1.9K Time 5V to <3V (calculated): PRIMARY = 5K & 10 uF ~ 27 msec RESERVE = 10K & 10 uF ~ 60 msec RESERVE_5V = 1.9K & 10 uF ~ 10 msec Measured PRIMARY ~ 76 msec RESERVE ~ 114 msec RESERVE5V ~ 38 msec
WARNING If you want to change nominals - you must check voltage at legs D+ and D- in 4 cases. My measuremets showed in [brackeds] for example Case #1 (PRIM OK, RESERVE OK): D+ < D- [2.4V < 4.8V] Case #2 (PRIM OK RESERVE BAD): D+ < D- [0V < 4.8V] Case #3 (PRIM BAD, RESERVE OK): D+ > D- [2.4V > 1.6V]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

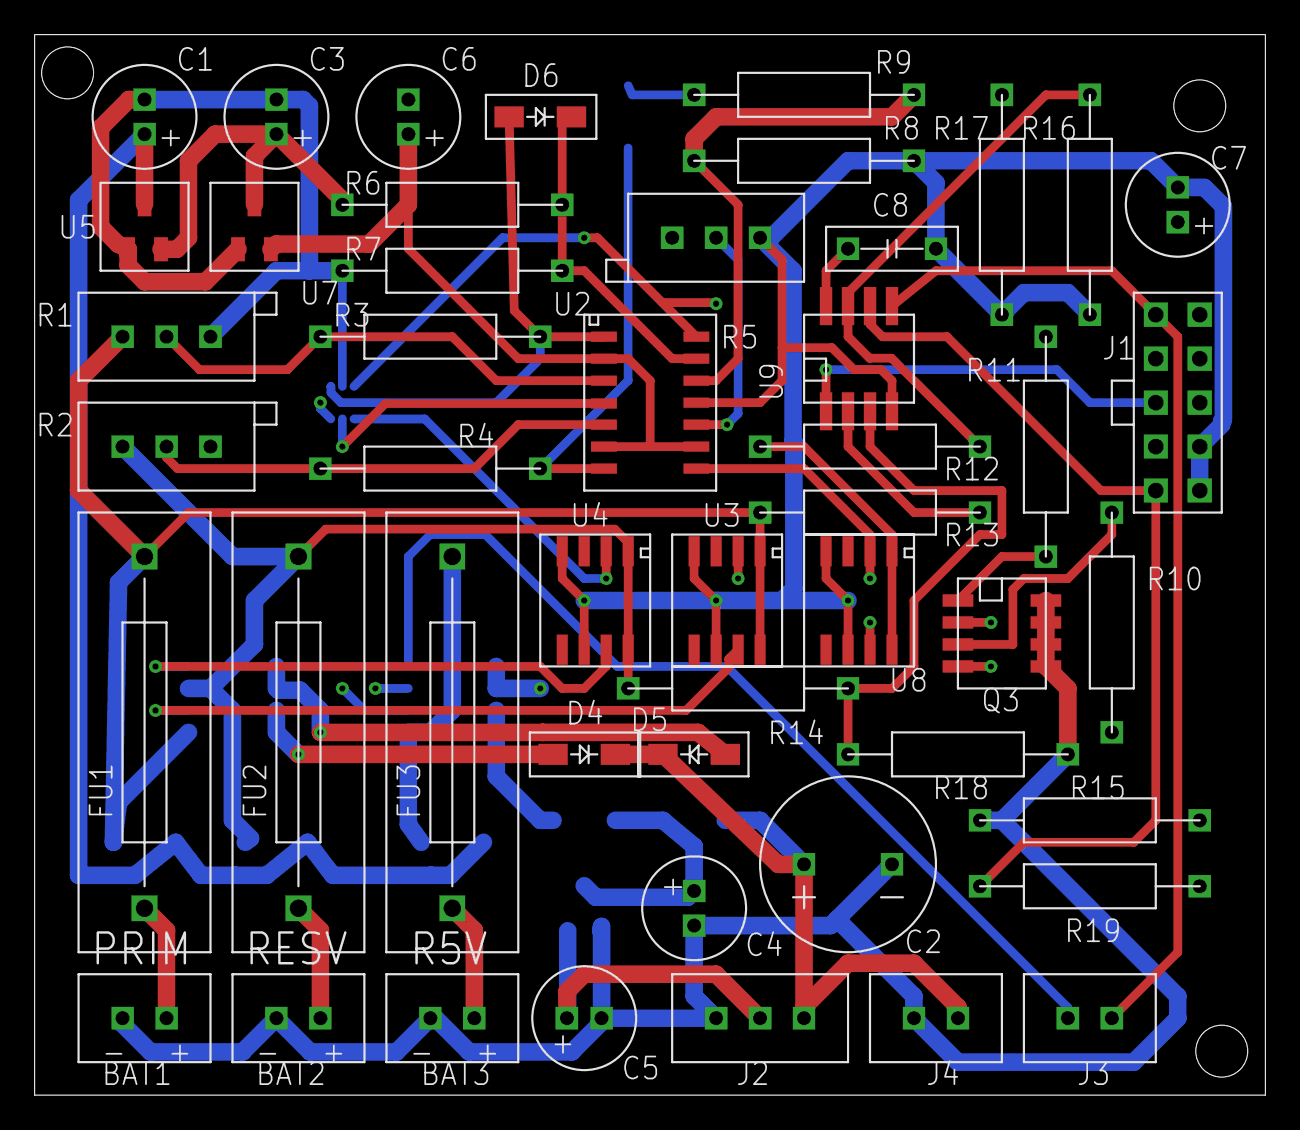
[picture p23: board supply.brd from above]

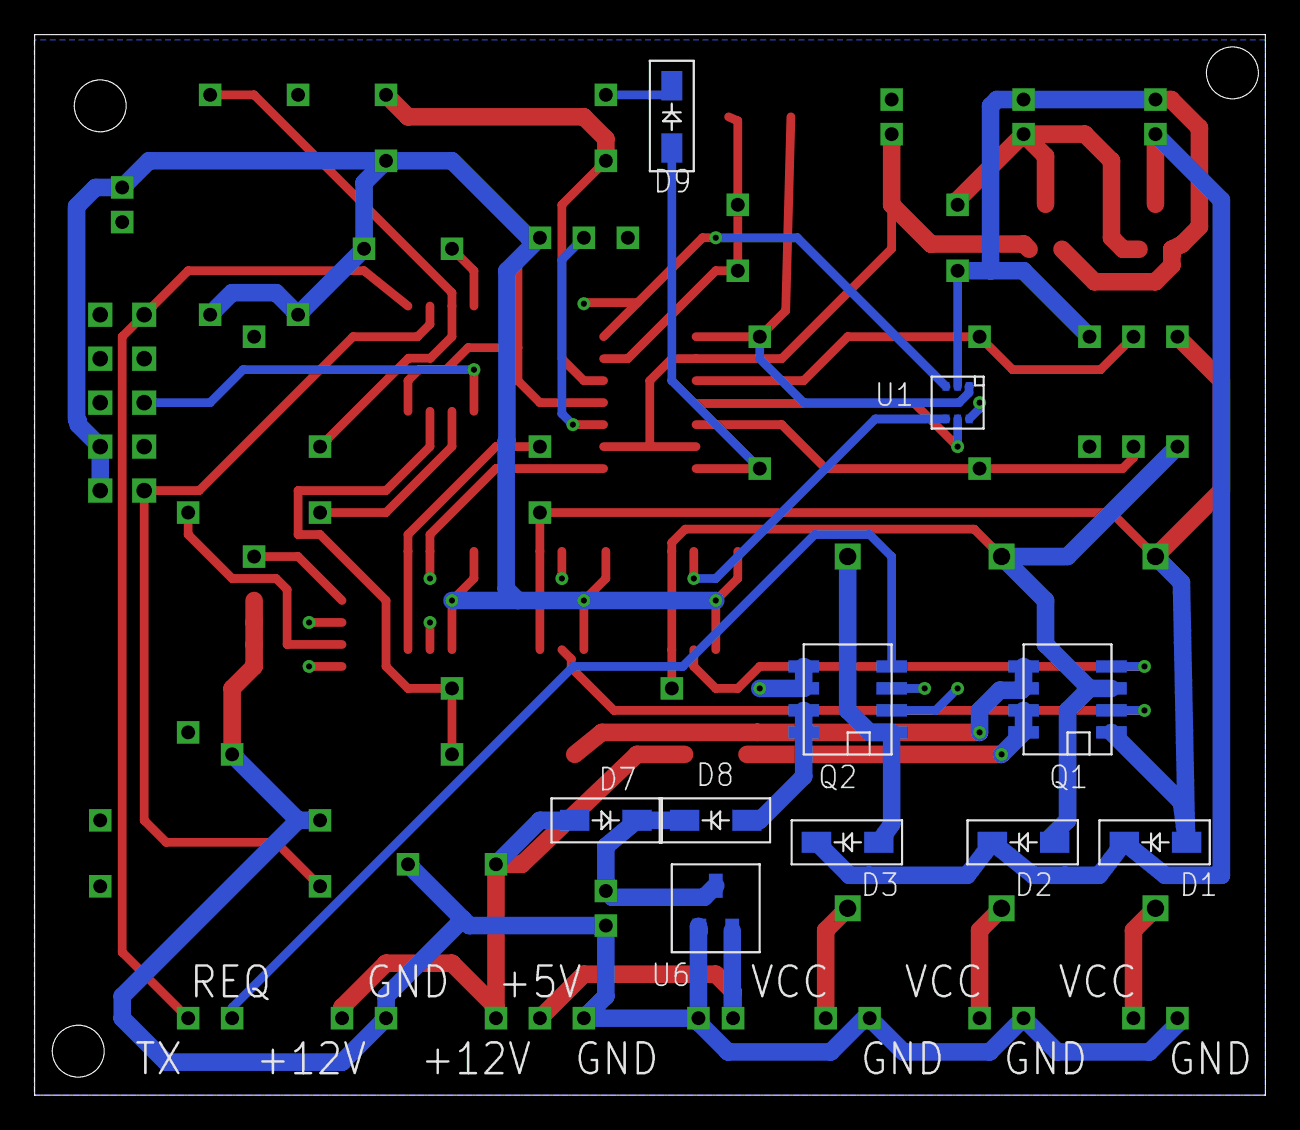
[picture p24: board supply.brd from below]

Board: 4 copper layers, 71.1 x 61.3 mm, 58 parts (10 on the bottom side), 42 nets.

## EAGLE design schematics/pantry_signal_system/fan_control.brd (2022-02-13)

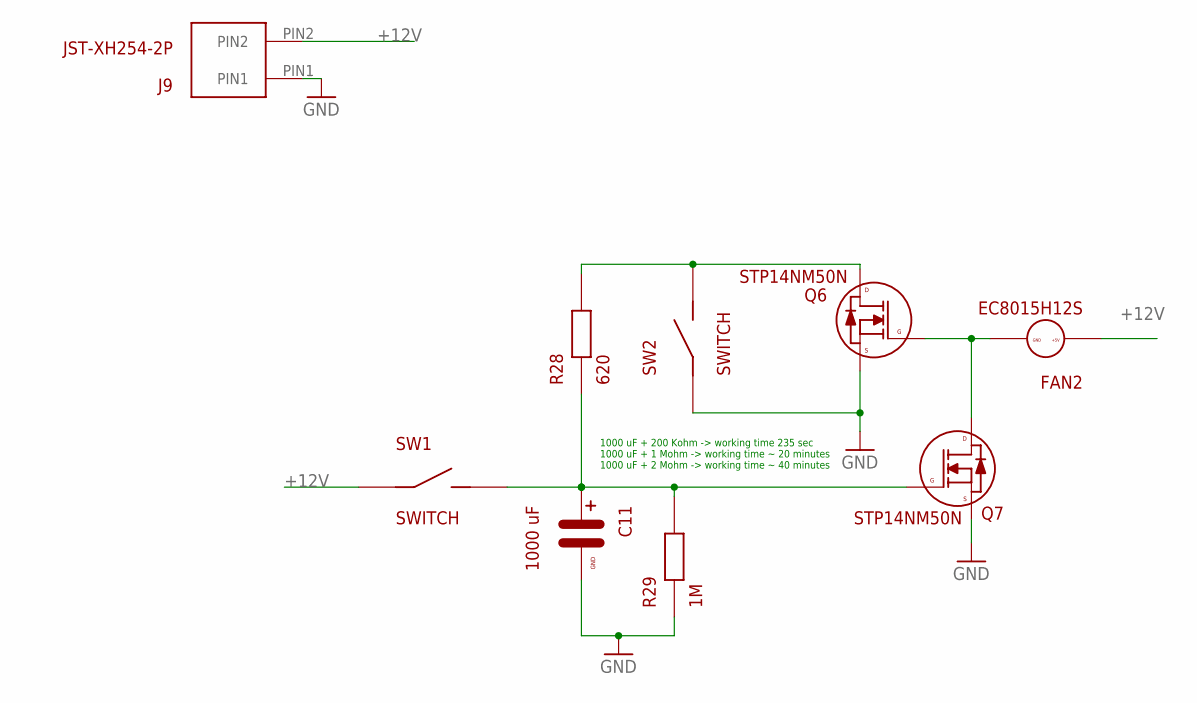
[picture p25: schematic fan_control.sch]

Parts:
C11: 1000 uF; C
FAN2: EC8015H12S; FAN_5V
J9: JST-XH254-2P
Q6, Q7: STP14NM50N; MOSFET_N
R28: 620; R
R29: 1M; R
SW1, SW2: SWITCH

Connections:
+12V: FAN2.VCC, J9.PIN2, SW1.P$1
GND: C11.PIN_GND, J9.PIN1, Q6.S, Q7.S, R29.P$1, SW2.P$1
unnamed: FAN2.GND, Q6.G, Q7.D
unnamed: C11.PIN_PLUS, Q7.G, R28.P$1, R29.P$2, SW1.P$2
unnamed: Q6.D, R28.P$2, SW2.P$2

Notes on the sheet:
1000 uF + 200 Kohm -> working time 235 sec 1000 uF + 1 Mohm -> working time ~ 20 minutes 1000 uF + 2 Mohm -> working time ~ 40 minutes

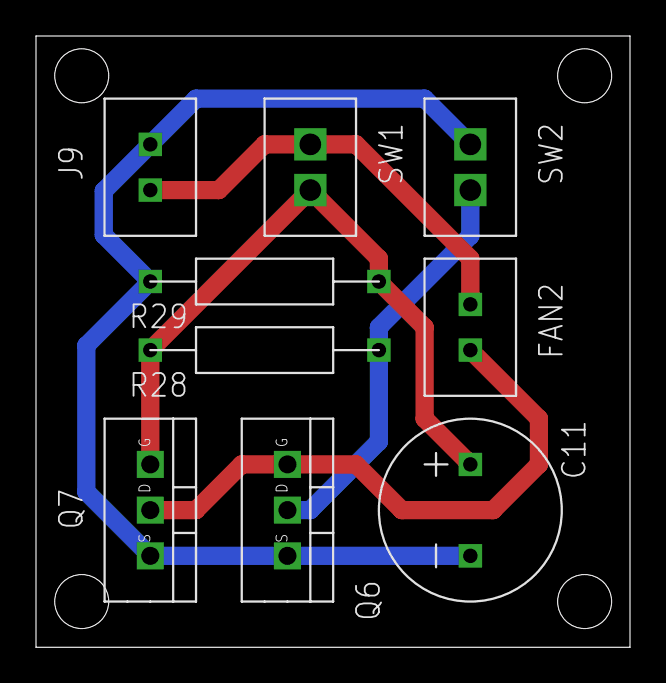
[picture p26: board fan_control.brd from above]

Board: 2 copper layers, 33.0 x 34.0 mm, 9 parts (0 on the bottom side), 5 nets.

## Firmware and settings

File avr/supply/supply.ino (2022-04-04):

#define PRIMARY_BATTERY_LEVEL     A3
#define RESERVE_BATTERY_LEVEL     A2
#define RESERVE_5V_LEVEL          A1
#define BATTERY_BATTERY_INUSE     1

typedef struct t_measure_vector_data {
  uint8_t fromvalue;
  uint16_t koef;
} t_measure_vector_data;

// Calibration coefs depends on actual resistance value you setup in schematics.

// *** How to calibrate voltage level measurement? ***
// 1. cleanup measure all vectors:
// const t_measure_vector_data PRIMARY_LEVEL_VECTOR[] = {};
// 2. upload scetch with empty vectors to ATTINY
// 3. enable SUPPLY_AVR_PRINT_CALIBRATION in logic-module/supply-api.ino
// 4. connect laboratory power supply to primary supply
// 5. setup power 6-7V on power supply and check serial output from logic-module.
// You will see lines like a
// active battery level XXX; B1: XXX; B2: YYYYY; B3: ZZZZZ
// 6. write B1 value to excel column A and actual supply voltage to excel column B
// 7. increase voltage on power supply on 1-2 volts and repeat point 6-7
// 8. continue untill voltage will increased to 14-15 volts
// 9. calculate KOEF using excel formula C = A * 100 / B 
// 10. calculate FROMVALUE using excel formula D = A / 10
// 11. write values to measure vector data in source code
// 12. repeat from point 4, but connect power supply to reserve supply and use B2 value at step 6
// 13. repeat from point 4, but connect power supply to reserve 5V supply and use B3 value at step 6
// 14. flush firmware with measure vectors to ATTINY. You will see actual voltage level
// --- Example ---
// voltage == 12.34 volt
// logic-module showed value 821 at point 6
// So: 
// .fromvalue = 82
// .koef = 6653

// *** How to calibrate battery percent usage? ***
// 1. process voltage level calibration as described below.
// 2. get absolute maximum value from your power supplies
// 3. multiply it on 10
// 4. write it into PRIMARY_MAX_LEVEL_X10, RESERVE_MAX_LEVEL_X10 and RESERVE_5V_MAX_LEVEL_X10
// 5. get absolute minimum value for your power supplies
// 6. multiply it on 10
// 7. write it into PRIMARY_MIN_LEVEL_X10, RESERVE_MIN_LEVEL_X10, RESERVE_5V_MIN_LEVEL_X10
// --- Example ---
// If absolute maximum voltage of your primary supply is 12.3 volts, you have to write in source code
// #define PRIMARY_MAX_LEVEL_X10 123
// If absolute minimum voltage of your primary supply is 9.1 volts, you have to write in source code
// #define PRIMARY_MIN_LEVEL_X10 91

// *** Calibration of current battery usage ***
// 1. enable SUPPLY_AVR_PRINT_CALIBRATION in logic-module/supply-api.ino
// 2. connect power supply to RESERVE_5V supply only
// 3. check serial output from logic-module.
// You will see lines like a
// active battery level XXX; B1: XXX; B2: YYYYY; B3: ZZZZZ
// 4. write "active battery level" value somewere
// 5. repeat 2-4 , but connect supply to PRIMARY supply only
// 6. repeat 2-4 , but connect supply to RESERVE supply only
// 7. Check stored values from 4, 5 and 6. Check - is conditions below correct? If values is incorrect - check resistance you used in schematics.
// 7.1 Value#4 < Value#5
// 7.2 Value#5 < Value#6
// 8. get any value between Value#4 and Value#5, and store it in
// #define THRESHOLD_INUSE_PRIMARY   50
// 9. get any value between Value#5 and Value#6, and store it in
// #define THRESHOLD_INUSE_RESERVE   90
// 10. flush firmware to ATTINY. You will see actual power supply in use

const t_measure_vector_data PRIMARY_LEVEL_VECTOR[] = {
    {
      .fromvalue = 0,
      .koef = 6685
    },
    {
      .fromvalue = 68,
      .koef = 6583
    },
    {
      .fromvalue = 75,
      .koef = 6452
    },
    {
      .fromvalue = 86,
      .koef = 6350
    }    
  };
const t_measure_vector_data RESERVE_LEVEL_VECTOR[] = {
    {
      .fromvalue = 0,
      .koef = 6293
    },
    {
      .fromvalue = 73,
      .koef = 6140
    },
    {
      .fromvalue = 86,
      .koef = 6116
    } 
  };
const t_measure_vector_data RESERVE5V_LEVEL_VECTOR[] = {
   {
      .fromvalue = 0,
      .koef = 6523
    },
    {
      .fromvalue = 54,
      .koef = 6404
    },
    {
      .fromvalue = 62,
      .koef = 6301
    },
    {
      .fromvalue = 68,
      .koef = 6245
    },
    {
      .fromvalue = 86,
      .koef = 6128
    } 
  };

#define PRIMARY_MIN_LEVEL_X10     100
#define PRIMARY_MAX_LEVEL_X10     130
#define RESERVE_MIN_LEVEL_X10     100
#define RESERVE_MAX_LEVEL_X10     130
#define RESERVE_5V_MIN_LEVEL_X10  50
#define RESERVE_5V_MAX_LEVEL_X10  118

#define THRESHOLD_INUSE_RESERVE   90
#define THRESHOLD_INUSE_PRIMARY   50

// min voltage level. Used to remove noise when supply not connected.
// All voltages below this value will be showed as zero.
#define MIN_VOLTAGE_LEVEL 50

// Headers in binary protocol. If you change this magic numbers - you must change same values in logic-module/supply-api.ino
#define HEADER_1  0x12
#define HEADER_2  0x13
#define HEADER_3  0x14
#define HEADER_BEGIN_BATTERY_LEVEL 0x55

uint16_t crc = 0;

void setup() {
  Serial.begin();

  pinMode(PRIMARY_BATTERY_LEVEL,   OUTPUT);
  pinMode(RESERVE_BATTERY_LEVEL,   OUTPUT);
  pinMode(RESERVE_5V_LEVEL,        OUTPUT);
  pinMode(BATTERY_BATTERY_INUSE,   OUTPUT);

  digitalWrite(PRIMARY_BATTERY_LEVEL,    LOW);
  digitalWrite(RESERVE_BATTERY_LEVEL,    LOW);
  digitalWrite(RESERVE_5V_LEVEL,         LOW);
  digitalWrite(BATTERY_BATTERY_INUSE,    LOW);

  delay(10);

  pinMode(PRIMARY_BATTERY_LEVEL,   INPUT);
  pinMode(RESERVE_BATTERY_LEVEL,   INPUT);
  pinMode(RESERVE_5V_LEVEL,        INPUT);

  delay(10);
}

uint8_t readCurrentBatteryLevel() {
  // power-up capacitor
  pinMode(BATTERY_BATTERY_INUSE,   OUTPUT);
  digitalWrite(BATTERY_BATTERY_INUSE, HIGH);
  delay(50);

  // power down and measure discharge time...
  unsigned long start = millis();
  pinMode(BATTERY_BATTERY_INUSE,   INPUT);
  while(digitalRead(BATTERY_BATTERY_INUSE) == HIGH);
  
  return (uint8_t) (millis() - start);
}

uint16_t readBatteryLevel(analog_pin_t pin) {
  uint16_t level_value = analogRead(pin);
  if (level_value < 200) {
    level_value = 0;
  }

  return level_value;
}

void serialWriteWithCRC(uint8_t serial_write_byte) { 
  crc += serial_write_byte; 
  Serial.write(serial_write_byte); 
}

void loop() {
  // read all values befor sending data to ensure no addition delays will be during sending process.
  uint8_t currentInUse = readCurrentBatteryLevel();
  uint16_t primaryLevel = readBatteryLevel(PRIMARY_BATTERY_LEVEL);
  uint16_t reserveLevel = readBatteryLevel(RESERVE_BATTERY_LEVEL);
  uint16_t reserve5vLevel = readBatteryLevel(RESERVE_5V_LEVEL);
  
  crc = 0;

  // write header
  Serial.write(HEADER_1);
  Serial.write(HEADER_2);
  Serial.write(HEADER_3);

  // write data
  sendBatteryLevel(primaryLevel,   PRIMARY_LEVEL_VECTOR,    sizeof(PRIMARY_LEVEL_VECTOR)/sizeof(t_measure_vector_data),    PRIMARY_MIN_LEVEL_X10,    PRIMARY_MAX_LEVEL_X10);
  sendBatteryLevel(reserveLevel,   RESERVE_LEVEL_VECTOR,    sizeof(RESERVE_LEVEL_VECTOR)/sizeof(t_measure_vector_data),    RESERVE_MIN_LEVEL_X10,    RESERVE_MAX_LEVEL_X10);
  sendBatteryLevel(reserve5vLevel, RESERVE5V_LEVEL_VECTOR,  sizeof(RESERVE5V_LEVEL_VECTOR)/sizeof(t_measure_vector_data),  RESERVE_5V_MIN_LEVEL_X10, RESERVE_5V_MAX_LEVEL_X10);
  sendCurrentBatteryNumber(currentInUse);

  // write CRC
  Serial.write(crc / 0xFF);
  Serial.write(crc % 0xFF);

  // await some time and repeat...
  delay(500);
}

void sendCurrentBatteryNumber(uint8_t currentInUse) {
  serialWriteWithCRC(currentInUse);

  uint8_t value;

  if (currentInUse >= THRESHOLD_INUSE_RESERVE) {
    value = 2;
  } else if (currentInUse >= THRESHOLD_INUSE_PRIMARY) {
    value = 1;
  } else {
    value = 3;
  }

  serialWriteWithCRC(value);
}

void sendBatteryLevel(uint16_t batteryLevel, const t_measure_vector_data* vector, uint8_t vector_size, uint8_t minLevel_x10, uint8_t maxLevel_x10) {
  uint8_t level = 0xFF;

  if (vector_size > 0) {
    vector_size--;
    while(true) {
      if (batteryLevel >= vector[vector_size].fromvalue || vector_size == 0) {
        level = (uint8_t) ((uint32_t)((uint32_t)batteryLevel * (uint32_t)1000) / (uint32_t)vector[vector_size].koef);
        break;
      }
      
      if (vector_size == 0) {
        break;
      }
      
      vector_size--;
    }
  }

  if (level < MIN_VOLTAGE_LEVEL) {
    level = 0;
  }

  serialWriteWithCRC(HEADER_BEGIN_BATTERY_LEVEL);

  // calibration raw data
  serialWriteWithCRC(batteryLevel / 0xFF);
  serialWriteWithCRC(batteryLevel % 0xFF);

  // voltage
  serialWriteWithCRC(level);

  // percent
  if (level < minLevel_x10) {
    serialWriteWithCRC(0);
  } else if (level > maxLevel_x10) {
    serialWriteWithCRC(100);
  } else {
    serialWriteWithCRC(((uint16_t)(level - minLevel_x10) * 100) / (maxLevel_x10 - minLevel_x10));
  }
}

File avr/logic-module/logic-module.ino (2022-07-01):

typedef struct ModuleData {
  uint8_t active_battery;
  uint8_t battery1_voltage_x10;
  uint8_t battery1_percent;
  uint8_t battery2_voltage_x10;
  uint8_t battery2_percent;
  uint8_t battery3_voltage_x10;
  uint8_t battery3_percent;
  bool outdoor_flooding_sensor_alarm;
  bool indoor_flooding_sensor_alarm;
  bool light_alarm;
  int16_t temperature_x10;
  uint16_t humidity_x10;
  bool is_air_dryer_on;
  bool open_door_alarm;
};

#define CONTINUE_MEASUREMEAT_AFTER_WAKEUP_OFF (20 * 1000L)
#define REQUEST_FULL_DATA_EVERY_MS            (5 * 60 * 1000L)
//#define REQUEST_FULL_DATA_EVERY_MS            10
#define PRINT_DATA_OBJECT                     false

unsigned long nextFullDataRequest = 0;
bool isInAlarmNow = false;

void setup() {
  Serial.begin(9600);
  while (!Serial);
  Serial.println("starting");

  delay(100);

  bme280_initialize();
  flooding_init();
  open_door_init();
  air_dryer_init();
  encrypter_init();
  lora_init();
  display_init();
  light_init();
  supply_api_init();
  wakeup_button_init();
  deepsleep_init();

  Serial.println("Init section done");
  delay(1000);
}

ModuleData * read_data(bool askSupply) {
  ModuleData * data2send = (ModuleData * ) malloc(sizeof(ModuleData));
  memset(data2send, 0, sizeof(ModuleData));

  data2send->outdoor_flooding_sensor_alarm = !flooding_outdoor_check_ok();
  data2send->indoor_flooding_sensor_alarm = !flooding_indoor_check_ok();
  data2send->light_alarm = is_light_on();
  data2send->temperature_x10 = (bme280_read_temperature() * 10);
  data2send->humidity_x10 = (bme280_read_humidity() * 10);
  data2send->open_door_alarm = !open_door_check_ok();
  data2send->is_air_dryer_on = air_dryer_enable_if_need(data2send->humidity_x10);

  if (askSupply) {
    uint8_t res = supply_api_read_with_retry(data2send);
    if (res) {
      Serial.print("supply-api read result: ");
      Serial.println(res);
    }
  }

#if PRINT_DATA_OBJECT
  Serial.print("active_battery == ");
  Serial.println(data2send->active_battery);
  Serial.print("battery1_voltage_x10 == ");
  Serial.println(data2send->battery1_voltage_x10);
  Serial.print("battery1_percent == ");
  Serial.println(data2send->battery1_percent);
  Serial.print("battery2_voltage_x10 == ");
  Serial.println(data2send->battery2_voltage_x10);
  Serial.print("battery2_percent == ");
  Serial.println(data2send->battery2_percent);
  Serial.print("battery3_voltage_x10 == ");
  Serial.println(data2send->battery3_voltage_x10);
  Serial.print("battery3_percent == ");
  Serial.println(data2send->battery3_percent);
  Serial.print("outdoor_flooding_sensor_alarm == ");
  Serial.println(data2send->outdoor_flooding_sensor_alarm);
  Serial.print("indoor_flooding_sensor_alarm == ");
  Serial.println(data2send->indoor_flooding_sensor_alarm);
  Serial.print("light_alarm == ");
  Serial.println(data2send->light_alarm);
  Serial.print("temperature_x10 == ");
  Serial.println(data2send->temperature_x10);
  Serial.print("humidity_x10 == ");
  Serial.println(data2send->humidity_x10);
  Serial.print("is_air_dryer_on == ");
  Serial.println(data2send->is_air_dryer_on);
  Serial.print("open_door_alarm == ");
  Serial.println(data2send->open_door_alarm);
#endif

  return data2send;
}

void loop() {
  if (wakeup_button_is_pressed()) {
    display_write_message("Starting...");
    
    while(wakeup_button_is_pressed()) {
      ModuleData * data2send = read_data(true);
      display_write(data2send);
      free(data2send);
      delay(2000);
    }

    unsigned long await = millis() + CONTINUE_MEASUREMEAT_AFTER_WAKEUP_OFF;
    while(await > millis()) {
      ModuleData * data2send = read_data(true);
      display_write(data2send);
      free(data2send);
      delay(2000);
    }

    display_off();
  } else {
    bool askFullData = nextFullDataRequest < millis();
    if (askFullData) {
      nextFullDataRequest = millis() + REQUEST_FULL_DATA_EVERY_MS;
    }
    
    ModuleData * data2send = read_data(askFullData);
    if (!askFullData && check_is_alarm(data2send)) {
      free(data2send);
      Serial.println("ALARM.. Requesting full data frame");
      askFullData = true;
      data2send = read_data(true);
    }

    if (askFullData) {
      lora_send(data2send, true);
    }
    
    free(data2send);
  }

  deepsleep_sleep();
}

bool check_is_alarm(const ModuleData * data2send) {
  bool alarm = data2send->outdoor_flooding_sensor_alarm || 
               data2send->indoor_flooding_sensor_alarm || 
               data2send->light_alarm || 
               data2send->open_door_alarm;
  
  if (alarm != isInAlarmNow) {
    isInAlarmNow = alarm;
    return true;
  } else {
    return false;
  }
}

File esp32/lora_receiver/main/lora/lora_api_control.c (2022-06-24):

#include "lora_api_control.h"

#include "time.h"
#include "freertos/FreeRTOS.h"
#include "freertos/task.h"
#include "driver/gpio.h"
#include "../log.h"

#define LORA_AWAIT_WAKEUP_TIMEOUT  3
#define LORA_AWAIT_GOSPEEP_TIMEOUT 3

int g_pin_m0m1;
int g_pin_aux;

esp_err_t lora_api_control_init(int pin_m0m1, int pin_aux) {
	g_pin_m0m1 = pin_m0m1;
	g_pin_aux  = pin_aux;

	gpio_config_t config = {
		.intr_type    = GPIO_INTR_DISABLE,
		.pin_bit_mask = (1ULL << g_pin_aux),
		.mode         = GPIO_MODE_INPUT,
		.pull_down_en = GPIO_PULLDOWN_DISABLE,
		.pull_up_en   = GPIO_PULLUP_ENABLE
	};

	esp_err_t res = gpio_config(&config);
	if (res) {
		ESP_LOGE(LORA_LOG, "gpio_config error: %d. on pin %d", res, g_pin_aux);
		return res;
	}

	config.pin_bit_mask = (1ULL << g_pin_m0m1);
	config.mode         = GPIO_MODE_OUTPUT;
	config.pull_up_en   = GPIO_PULLUP_DISABLE;

	res = gpio_config(&config);
	if (res) {
		ESP_LOGE(LORA_LOG, "gpio_config error: %d. on pin %d", res, g_pin_m0m1);
		return res;
	}

	return ESP_OK;
}


void lora_api_control_go_sleep() {
	time_t awaitUntill;
	time(&awaitUntill);
	awaitUntill += LORA_AWAIT_GOSPEEP_TIMEOUT;
	while (gpio_get_level(g_pin_aux) == 0) {
		// await data transmittion
		time_t now;
		time(&now);
		if (now < awaitUntill) {
			ESP_LOGW(LORA_LOG, "lora_api_control_go_sleep :: Aux await timeout");
			break;
		}
	}

	gpio_set_level(g_pin_m0m1, 1);
	vTaskDelay(2 / portTICK_PERIOD_MS);
}

void lora_api_control_wakeup() {
	time_t awaitUntill;
	time(&awaitUntill);
	awaitUntill += LORA_AWAIT_WAKEUP_TIMEOUT;

	gpio_set_level(g_pin_m0m1, 0);

	while(gpio_get_level(g_pin_aux) == 1) {
		// Await module start waking up
		time_t now;
		time(&now);
		if (now < awaitUntill) {
			ESP_LOGW(LORA_LOG, "lora_api_control_wakeup :: Aux await LEVEL 1 timeout");
			break;
		}
	}

	while(gpio_get_level(g_pin_aux) == 0) {
		// Await module wake up
		time_t now;
		time(&now);
		if (now < awaitUntill) {
			ESP_LOGW(LORA_LOG, "lora_api_control_wakeup :: Aux await LEVEL 0 timeout");
			break;
		}
	}
}

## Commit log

2021-11-15 Start creating schema
    [full_schema.sch]
2021-11-15 Initial schema for supply subsystem
    [full_schema.sch]
2021-11-16 Initial schema for logic module
    [full_schema.sch]
2021-11-16 Initial schema for fan system
    [full_schema.sch]
2021-11-16 added some nominals
    [full_schema.sch]
2021-11-20 Added +5V reserve supply and auto-enable schema wich switched it on when primary and reserve 12V supply discharged
    [full_schema.sch]
2021-11-20 Added nominals for air fan
    [full_schema.sch]
2021-11-20 Fixed comment for working time of air fan
    [full_schema.sch]
2021-11-25 changed mosfet drivers to FAN73611
    [full_schema.sch]
2021-12-02 3D model for SOIC8-chips adapter
    [sioc8_to_dip8.stl, soic8_to_dip8-top.FCStd, soic8_to_dip8-top.stl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]
2021-12-03 Finalized debug model for SOIC8 chips
    [soic8_to_dip8-top.FCStd, soic8_to_dip8-top.stl]
2021-12-03 Added model for SOC32A debug adapter (bottom side)
    [soc23a-adapter.stl, sot23a_adapter.FCStd]
2021-12-03 added topside model for SOC23A debug adapter
    [soc23a-adapter-top.stl, soc23a-adapter.stl, sot23a_adapter-top.FCStd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]
2021-12-09 Air drier schema works
    [full_schema.sch, soc23a-adapter-top.stl, sot23a_adapter-top.FCStd]
2021-12-10 Lora module FW and HW works. Encrypted connection betweed modules estabilished
    [full_schema.sch]
2021-12-11 Added firmware for supply module (not tested yet)
    [full_schema.sch]
2021-12-12 Display driver and schema ready
    [full_schema.sch]
2021-12-12 Light sensor is ready now
2021-12-12 Start working under supply schema
    [full_schema.sch]
2021-12-12 Added programmer connector for ATTiny
    [full_schema.sch]
2022-01-12 Working under supplu control
    [attiny-adapter.FCStd, attiny-adapter.stl, battery-test-box.FCStd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]
2022-01-12 Continue working under supply control schematics. Changed N-channel mosfets to P-channel mosfets. Small changes in logic control module
    [full_schema.sch]
2022-01-15 Continue working under supply schematics and supply controller firmware
    [full_schema.sch]
2022-01-16 working under supply schematics. I think I solved problem with 'current battery in use' signal reading
    [full_schema.sch]
2022-01-18 and another iteration for suplly avr data reading
    [full_schema.sch]
2022-01-25 Supply controller schematics and firmware ready
    [full_schema.sch]
2022-01-26 working under supply schematics
    [full_schema.sch]
2022-01-31 I finished supply control schematics
    [full_schema.sch]
2022-02-01 start working under wakeup button and deep sleep mode
2022-02-02 1. BME280 works fine. 2. I have problem with I2C bus when display connected, but unpowerd. I will investigate this problem
    [bme280.ino, logic-module.ino]
2022-02-03 Added 3D model of air dryer
    [air-dryer-box.stl, air-dryer-container-box.stl, air-dryer-container.stl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]
2022-02-03 renamed stl file
    [air-dryer-container-cup.stl]
2022-02-03 remove deleted file
    [air-dryer-container-box.stl]
2022-02-08 Try to fix problem with I2C bus and display module
    [full_schema.sch]
2022-02-08 PINs in source code assigned as in schematics
2022-02-09 wakeup button, deepsleep & display works fine
2022-02-09 ADded lora receiver schema
    [full_schema.sch, lora_receiver.sch]
2022-02-10 lora receiver - finished ESP32 firmware (not tested yet)
2022-02-10 Fix problem with signal level 3V3 <-> 5V for lora
    [lora_receiver.sch]
2022-02-11 Preparing primary schema for creating board - all packages setup
    [full_schema.sch, lora_receiver.sch]
2022-02-13 Changed LoRa Receiver schematics to use level converter modules
    [lora_receiver.sch]
2022-02-13 Added board for LoRa receiver
    [lora_receiver.brd, lora_receiver.sch]
2022-02-13 Added FAN Control board
    [fan_control.brd, fan_control.sch, full_schema.sch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]
2022-02-13 Added Logic Module board
    [fan_control.sch, logic_module.brd, logic_module.sch]
2022-02-13 Added supply board
    [supply.brd, supply.sch]
2022-02-14 Boards checked, some packages changed, library synced with this project
    [supply.brd, supply.sch]
2022-02-14 I submited order for this boards....
2022-02-14 Fixed issue in air dryer container 3D model
    [air-dryer-container-cup.stl, air-dryer-container.stl, air-dryer.FCStd]
2022-02-14 air fan income - initial version, I will reduce it's size later
    [air-fan-income-filter.stl, air-fan-income-plate.stl, air-fan-income-top.stl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]
2022-02-15 Air Fan Income redesigned
    [air-fan-income-filter.stl, air-fan-income-plate.stl, air-fan-income-support.stl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]
2022-02-15 Added Air Fan Outcome 3D model
    [air-fan-outcome-filter.stl, air-fan-outcome-plate.stl, air-fan-outcome-support.stl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]
2022-03-03 3D models for air income and air dryer
    [air-dryer-box.stl, air-dryer-cup.stl, air-dryer-pin.stl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]
2022-03-19 1. Fixed issues in boards and firmwares
    [air-fan-box-box.stl, air-fan-box-top.stl, air-fan-box.FCStd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]
2022-03-19 Actual board
2022-03-22 Added 3D Models for boxes
    [control-module-box-back.stl, control-module-box-front.stl, control-module-box.FCStd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]
2022-04-04 Preparing to assemble device
    [23a-battery-container-box.stl, 23a-battery-container.FCStd, control-module-box-front.stl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]
2022-04-04 Fixed issue with connection between supply and logic module
    [supply.ino]
2022-04-20 Changes in schematics, changes in source code. Current version works too, but I changed boards to fix some possible errors
    [logic_module.brd, logic_module.sch, lora_receiver.brd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]
2022-06-24 Debugging logic module firmware, estabilishing LoRa connection....
    [full_schema.sch, logic_module.brd, logic_module.sch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]
2022-07-01 Capacitor nominal changed in logic-module to fix problem with chip restart when LoRa sends data with high current consumption
    [logic_module.brd, logic_module.sch]
2022-07-20 working under 3d models
    [internal-flooding-sensor.FCStd, internal-flooding-sensor.stl, pantry_box-box.stl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]
2022-07-25 working under 3D model
    [pantry_box-test-board-logic.stl, pantry_box-test-board-supply.stl, pantry_box-test-capacitor.stl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]
2022-07-25 Changes in 3D model
    [pantry_box.FCStd]
2022-12-06 Changed 3D models to actuall printed, changed firmware to actually flushed
    [flooding-sensor-left-side.stl, flooding-sensor-right-side.stl, flooding-sensor.FCStd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]
2024-03-07 project finished
    [lora_receiver-bottom.stl, lora_receiver-box.stl, lora_receiver-cup.stl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]
